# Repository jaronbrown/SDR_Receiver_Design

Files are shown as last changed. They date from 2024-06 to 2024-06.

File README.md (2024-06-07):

# Walla Walla University ENGR357 SDR Design Winter 2024

## Goals
- Continuous Coverage from 5-30 MHz and AM coverage (540-1700 kHz)
- Tune to AM by mixing up to 10.7 MHz then using the Tayloe detector to down-sample to 0-48 kHz

## Design
 - Incorporates a two stage mixing approach in order to achieve wider bandwidth with Si5351 quadrature limitations 
 - Utilizes a Tayloe detector for down-conversion of RF signals.
 - Optional second mixer to bring up AM frequencies (540-1700 kHz) so they can be sampled by Tayloe detector.
 - Input Stage: Automatic Band Pass Filters with optional AM mixer. Includes antenna ground isolation.
 - Output Stage: Quadrature signals amplified with 84 kHz low pass filter. Sampled directly with on-board ADC (48 kHz Nyquist) or output over 3.5mm audio jack. The larger LPF passband (84 kHz) minimizes ripple.
 - Raspberry Pi Pico W Controller with LDO (TPS7A8001DRBR) for cleaner +4V5 (derived from +5V USB).
 - H/W Controlled BPF multiplexors, i2c controlled 3-output VLO (Si5351), and i2s compatible ADC (PCM1808PWR).

## ltspice Simulations
Various core elements of the design were simulated to test their functionality. Notable simulations include a [Monte Carlo simulation](spice/BPF_monte_carlo.asc) of the three bandpass filters (frequency response shown below) to determine effects of component tolerances and a [simulation of the Tayloe detector](spice/Tayloe_test.asc), along with its "differential" amplifiers. The Tayloe detector input is a 1 $\mu V$ sinewave and the output (of the I channel) can be seen in the graph below. In the actual implementation, there is a 1 $\mu F$ blocking capacitor before the ADC and audio jack, but this is omitted for sake of simulation. This would remove the 2.25V DC offset.

Bandpass Filters
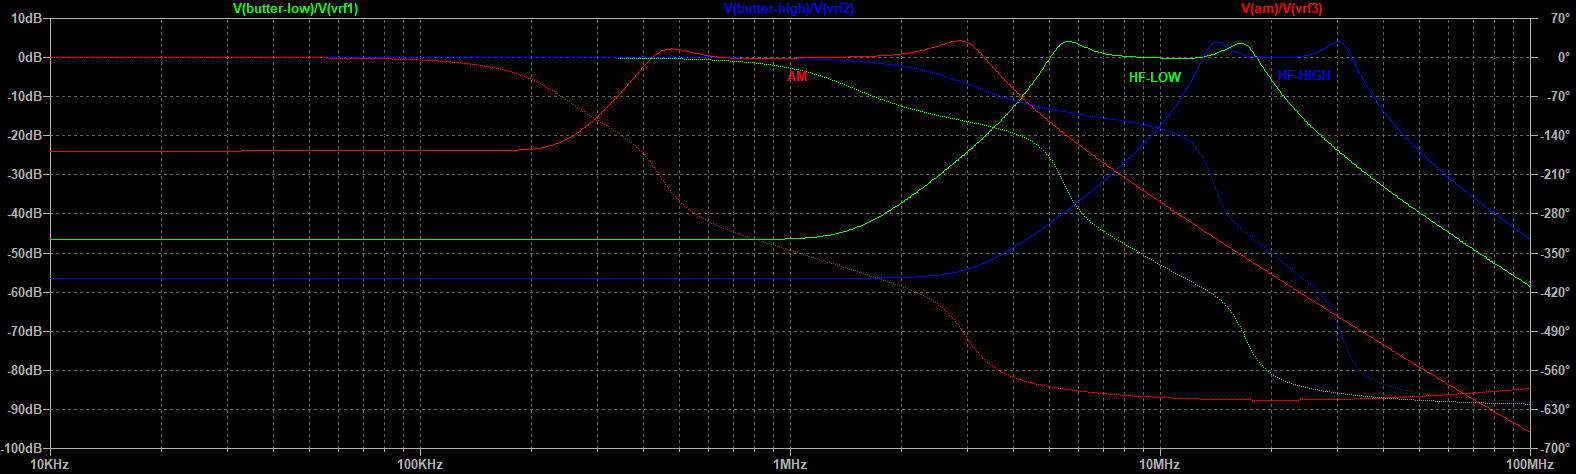
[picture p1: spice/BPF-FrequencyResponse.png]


Tayloe Detector
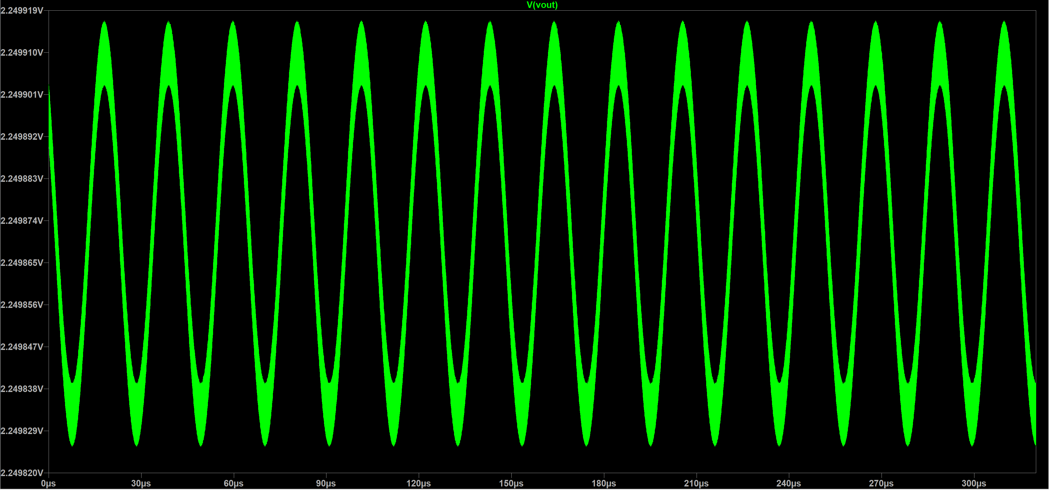
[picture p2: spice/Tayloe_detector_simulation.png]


## Fabrication Information
The boards tested were fabricated by [JLCPCB](jlcpcb.com). They also installed all the surface-mount components--LCSC part numbers included in schematic. Total fabrication cost (including building the boards) from JLCPCB was about $120 USD for 5 boards. The [build plan](BuildPlan.md) was followed for assembling the boards and testing their functionality. The specifications for the inductors and transformer used, can be found in [Inductors](Inductors.md).

## Software
### Python
The software for the Raspberry Pi Pico W consists of three microPython files: [main.py](python/main.py), [radio.py](python/radio.py), and [si5351.py](python/si5351.py). All three files should be loaded onto the Pico.

The microPython module to control the SI5351, [si5351.py](python/si5351.py), was provided by [https://github.com/thaaraak/Tinypico-Radio/tree/master](https://github.com/thaaraak/Tinypico-Radio/tree/master). Some minor changes were made to the ```outputs_enabled``` setter in order to allow individual clock enabling/disabling--used for the AM mixer local oscillator.

The radio control is handled by [radio.py](python/radio.py) which after initializing a ```Radio```, ```run()``` can be used to parse Quisk commands and automatically control bandpass filter selection (based on frequency) and frequency. The bandpass filters can also be controlled manually by entering "BAND,AUTO" to allow for manual testing and use of the built in bypass capacitor. Frequencies from 4-32 MHz are handled via the HF HIGH/LOW BPFs with a single stage of mixing. Frequencies from 0.4-4 MHz are handled via AM mixing (due to the SI5351 not maintaining quadrature below 4 MHz). When switching from AM bands back to HF the SI5351 control is reinitialized to prevent unpredictable clock drift.

Currently there is no support for WiFi control/data transmit, nor is there support for the on-board ADC. This would require migrating to C for DMA. This is coming soon TM.

## Quisk
This SDR is designed to be used with Quisk (https://james.ahlstrom.name/quisk/). Some basic Quisk device configs are provided in [quisk](quisk/). Currently there is no custom widget support for bandpass selection and AM offsets (for tuning away from center).

An optional [Dockerfile](Dockerfile) and sample [start script](startDocker.sh.sample) is provided to run Quisk via Docker--though this requires proper ```/dev/ttyACM0``` permissions, pulseaudio, and xserver. If running on Windows via WSL the aforementioned packages should be installed as well as utilizing usbipd-win (https://james.ahlstrom.name/quisk/) to passthrough the Pico connection.

## Case
stl files for a 3d printable [case](case) are included. Note that because the board does not have any mounting holes the case is a friction fit--consider adjusting tolerances when printing.

## Testing
Testing revealed the radio functions over the planned 10-30 MHz as well as the AM commercial frequencies (using the second mixer), though some signal overlap is apparent for AM. The bandpass filters were characterized using a signal generator and a spectrum analyzer.

### AM Bandpass Filter Characterization
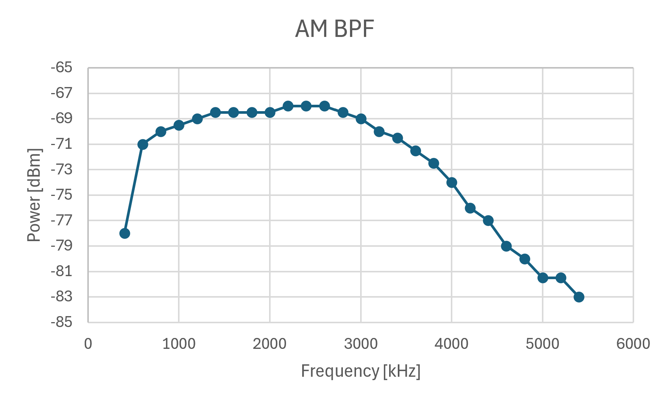
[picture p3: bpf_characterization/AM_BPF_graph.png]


### Low HF Bandpass Filter Characterization
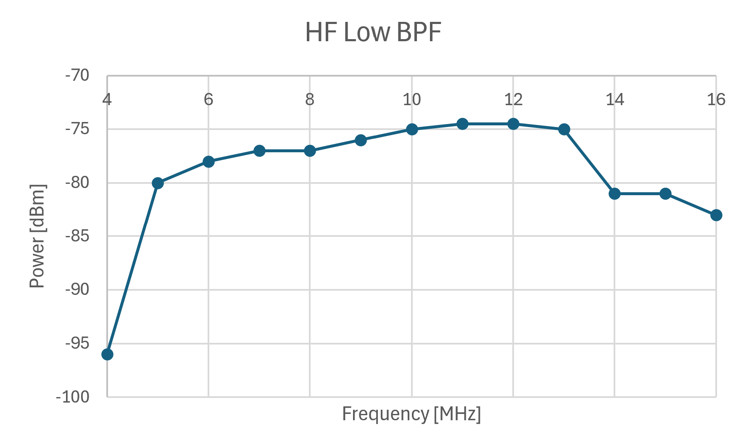
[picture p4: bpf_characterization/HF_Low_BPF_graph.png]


### High HF Bandpass Filter Characterization
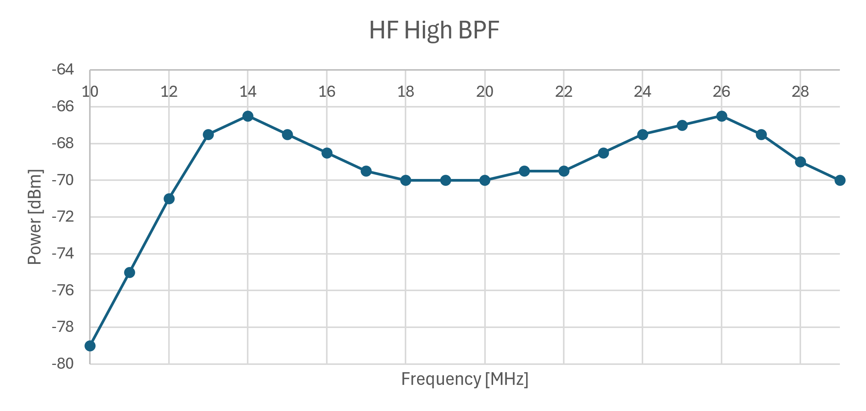
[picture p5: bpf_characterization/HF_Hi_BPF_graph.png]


## KiCAD Schematic
### Complete Block Diagram


### Automatic Band Pass Filter


### AM Handling: Filters and Upconversion


### 3rd Order Butterworth BPF 5-18 MHz


### 3rd Order Butterworth BPF 13-32.7 MHz


### IQ Tayloe Detector & 84kHz IF filter


### SDR Controller


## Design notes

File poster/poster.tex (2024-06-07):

% Gemini theme
% https://github.com/anishathalye/gemini

\documentclass[final]{beamer}

% ====================
% Packages
% ====================

\usepackage[T1]{fontenc}
\usepackage{lmodern}
\usepackage[size=custom,width=121.92,height=91.44,scale=1.0]{beamerposter}
\usetheme{gemini}
\usecolortheme{wwu}
\usepackage{graphicx}
\usepackage{booktabs}
\usepackage{tikz}
\usetikzlibrary{graphs,graphs.standard,arrows.meta}
\usepackage{pgfplots}
\usepackage[square,numbers]{natbib}
\pgfplotsset{compat=1.14}
\usepackage{anyfontsize}

%\usepackage{etoolbox}
\newcommand{\framedtext}[1]{%
\par%
\noindent\fbox{%
    \parbox{\dimexpr\linewidth-2\fboxsep-2\fboxrule}{#1}%
}%
}

% ====================
% Lengths
% ====================

% If you have N columns, choose \sepwidth and \colwidth such that
% (N+1)*\sepwidth + N*\colwidth = \paperwidth
\newlength{\sepwidth}
\newlength{\colwidth}
\setlength{\sepwidth}{0.025\paperwidth}
\setlength{\colwidth}{0.3\paperwidth}

\newcommand{\separatorcolumn}{\begin{column}{\sepwidth}\end{column}}

% ====================
% Title
% ====================

\title{Software-Defined Radio\\ An Electrical Engineering Project}

\author{Jaron Brown \and Ethan Jansen}

\institute[shortinst]{Edward F. Cross School of Engineering, Walla Walla University, College Place, Washington}

% ====================
% Footer (optional)
% ====================

\footercontent{
  \href{https://gitlab.cs.wallawalla.edu/browja/engr357-receiver-design}{https://gitlab.cs.wallawalla.edu/browja/engr357-receiver-design}
  %\hfill\href{mailto:email@wallawalla.edu}{email@wallawalla.edu}
}
% (can be left out to remove footer)

% ====================
% Logo (optional)
% ====================

% use this to include logos on the left and/or right side of the header:
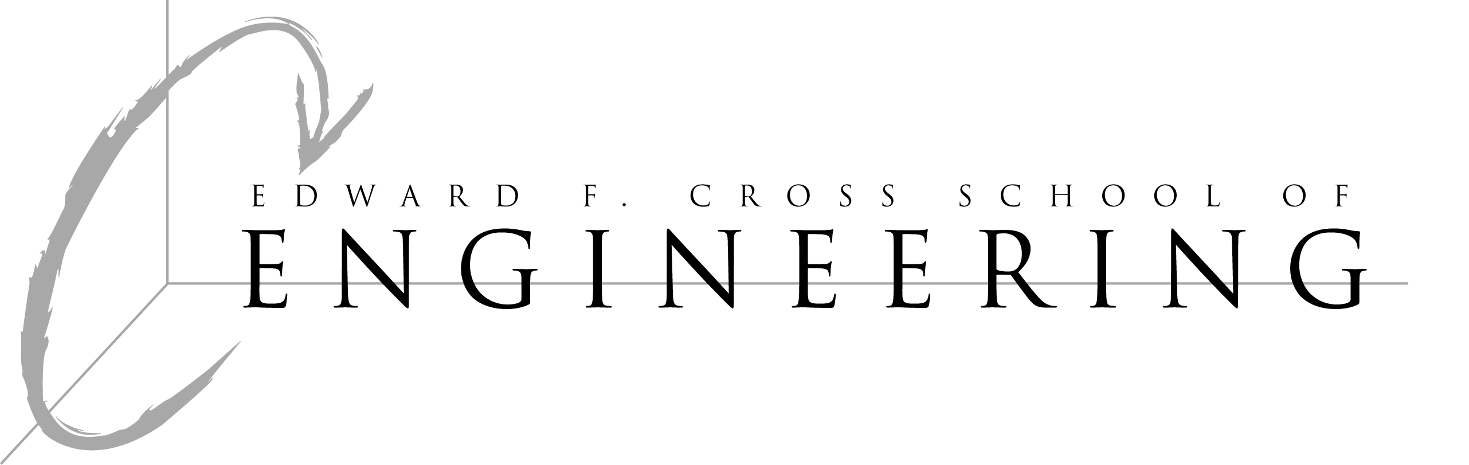
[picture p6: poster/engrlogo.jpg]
\logoright{}
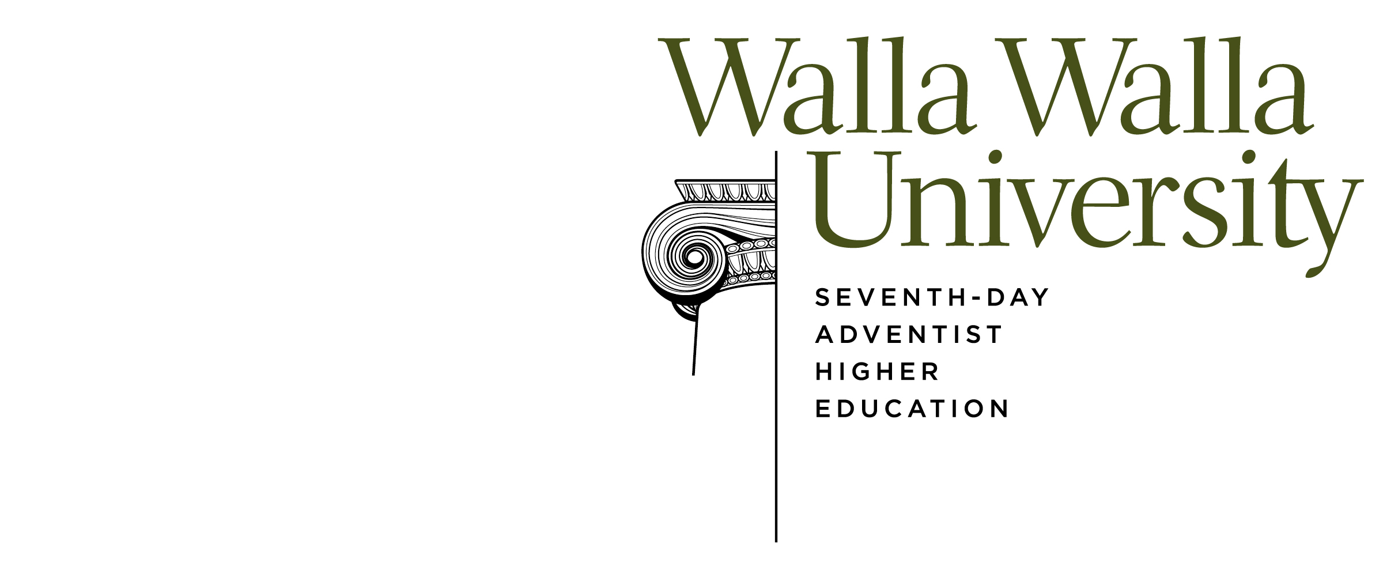
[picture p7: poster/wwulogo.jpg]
\logoleft{}

% ====================
% Body
% ====================

\begin{document}

\begin{frame}[t]
\begin{columns}[t]
\separatorcolumn

\begin{column}{\colwidth}

  \begin{exampleblock}{Introduction}

    \begin{figure}
      \centering
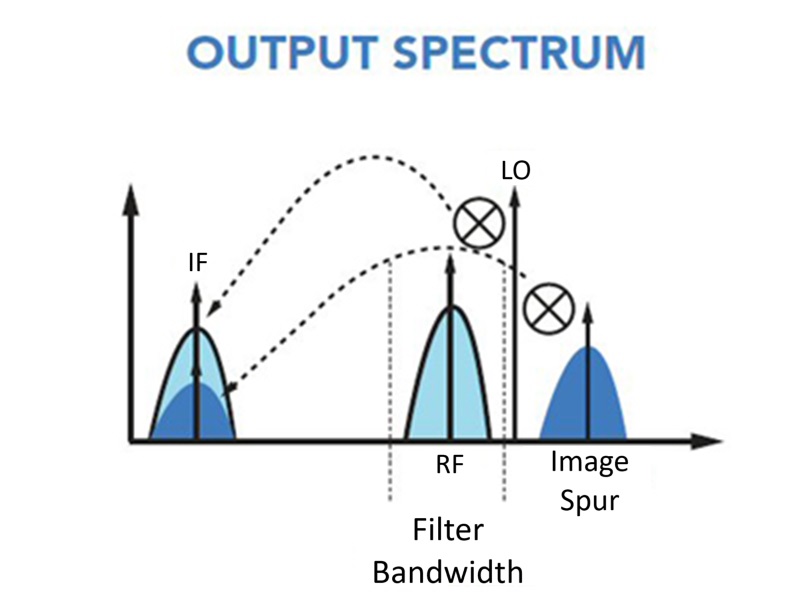
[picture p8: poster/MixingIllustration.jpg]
      
      \caption{Mixing a radio frequency (RF) signal down to an intermediate frequency (IF) (audio) signal. Shows a spur being mixed down to the same IF as the desired signal as it is the same distance from the local oscillator (LO) frequency as RF. \cite{mixing}}
    \end{figure}
    
  \end{exampleblock}

  \begin{block}{Section 1}

  \end{block}

  \begin{block}{Section 2}

  \end{block}

\end{column}

\separatorcolumn

\begin{column}{\colwidth}

  \begin{block}{Section 1}
    
    \begin{figure}
      \centering
      
      \caption{SDR Schematic showing the analog quadrature mixer (left) and the digital controller (right).}
    \end{figure}

    \begin{figure}
      \centering
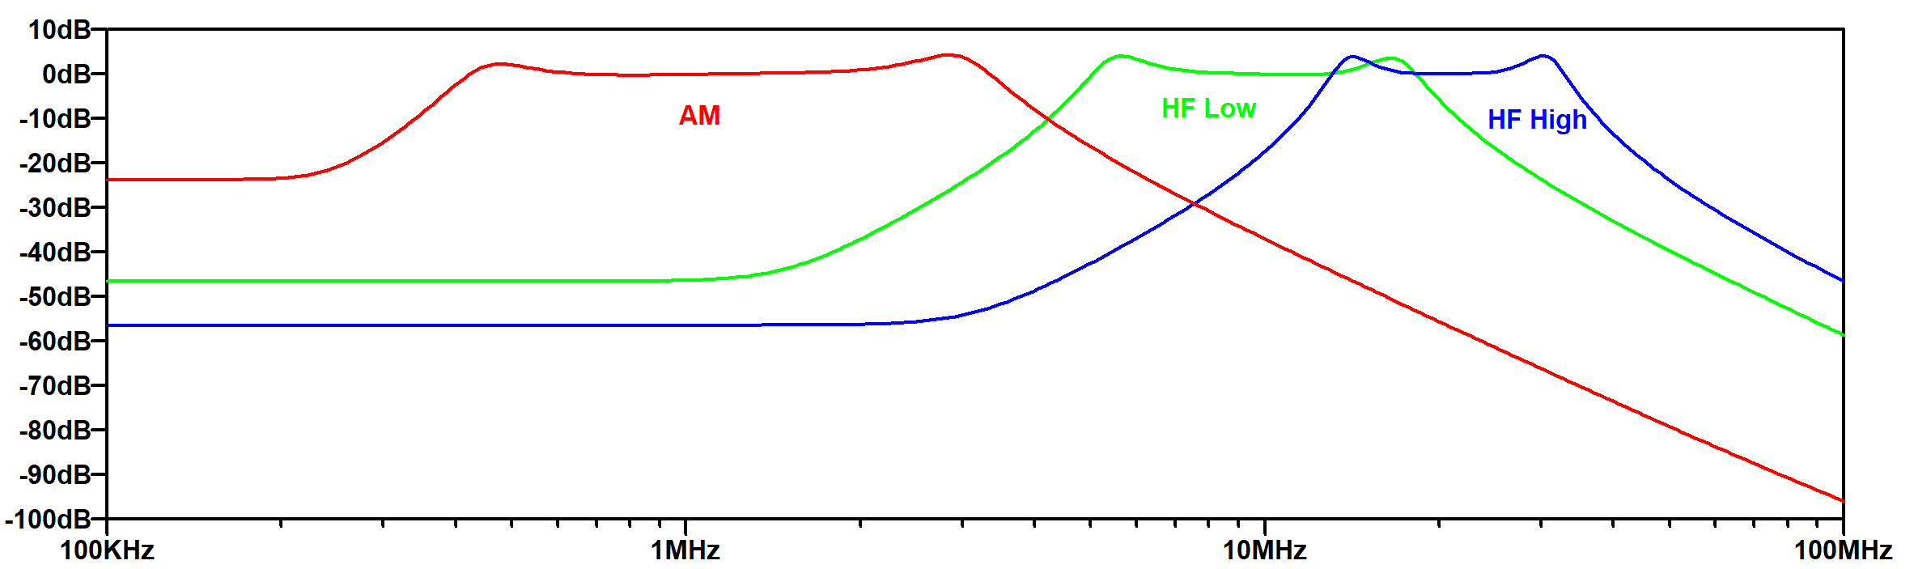
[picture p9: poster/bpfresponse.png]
      
      \caption{Simulation of the different band-pass filters.}
    \end{figure}

    \begin{figure}
      \centering
      
      \caption{SDR circuit board layout. Shows the part locations and traces connecting them.}
    \end{figure}

    \begin{figure}
      \centering
      
      \caption{The completed SDR. A physical, fully manufactured board.}
    \end{figure}

  \end{block}

  \begin{block}{Section 2}

  \end{block}

\end{column}

\separatorcolumn

\begin{column}{\colwidth}

  \begin{block}{Section 1}

    \begin{figure}
      \centering
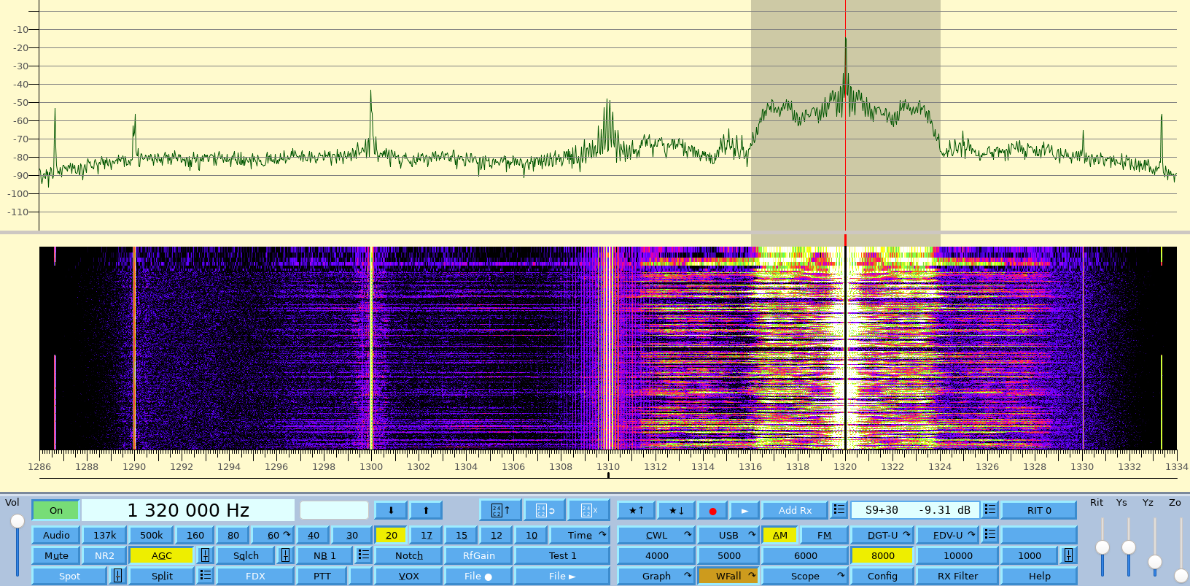
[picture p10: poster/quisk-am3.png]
      
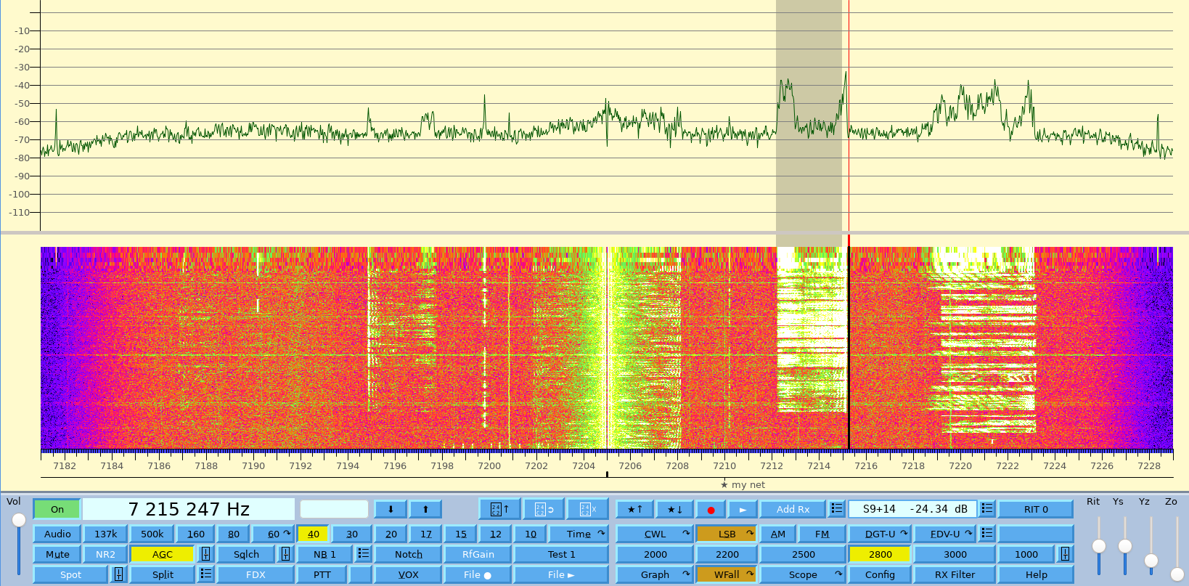
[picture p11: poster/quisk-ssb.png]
      
      \caption{Quisk SDR software \cite{quisk}. Shows the waterfall display, the audio spectrum, and device control. (Top) AM demodulation at 1.3MHz. (Bottom) SSB demodulation at 7.2MHz.}
    \end{figure}

  \end{block}
  
  \begin{block}{Section 2}

  \end{block}

  \begin{block}{References}

    \nocite{*} % don't cite everything
    \footnotesize{\bibliographystyle{plain}\bibliography{poster}}

  \end{block}

\end{column}

\separatorcolumn
\end{columns}
\end{frame}

\end{document}

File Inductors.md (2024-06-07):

| ID | Value | Freq. Range (Mhz) | Core | Turns | Wire Length (cm)|
|:--:|:-----:|:---:|:----:|:-----:|:---:|
| T1 | 1:1 - 500 $\Omega$ | 0.4-30 | FT37-43 | 24 | 36 |
| L1, L3 | 620nH | 5-18 | T37-6 | 14 | 23 |
| L2 | 560nH | 5-18 | T37-6 | 14 | 23 |
| L4, L6 | 2.7uH | 0.4-3.3 | T50-2 | 23 | 46 |
| L5 | 9.1uH | 0.4-3.3 | T50-2 | 43 | 79 |
| L7, L9 | 390nH | 13-33 | T37-6 | 11 | 20 |
| L8 | 180nH | 13-33 | T37-6 | 8 | 15 |

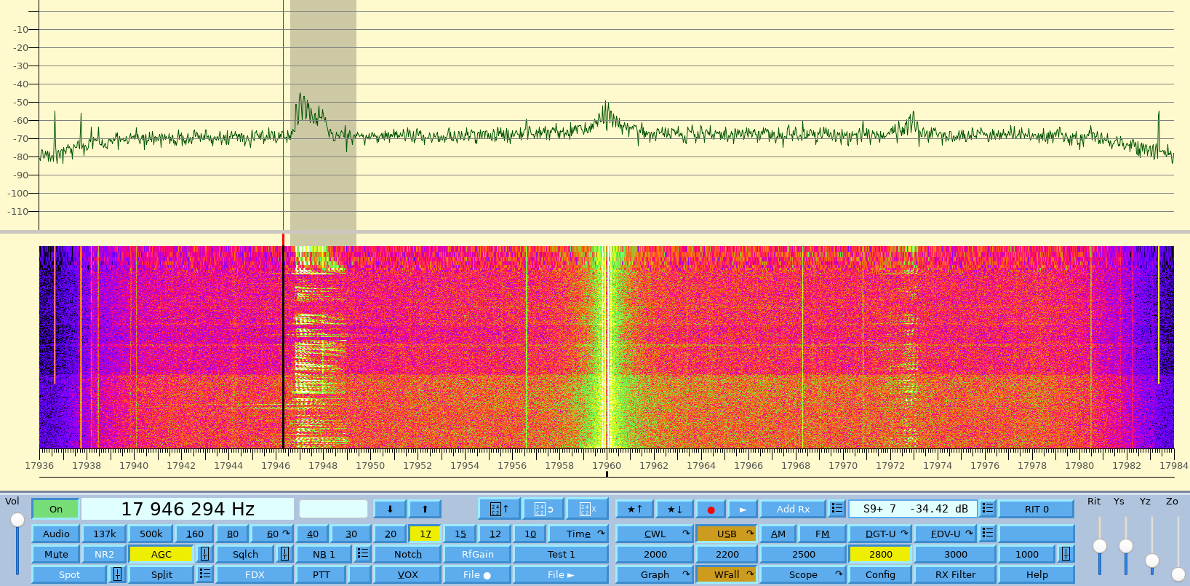
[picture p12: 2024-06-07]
poster/quisk-ssb3.png

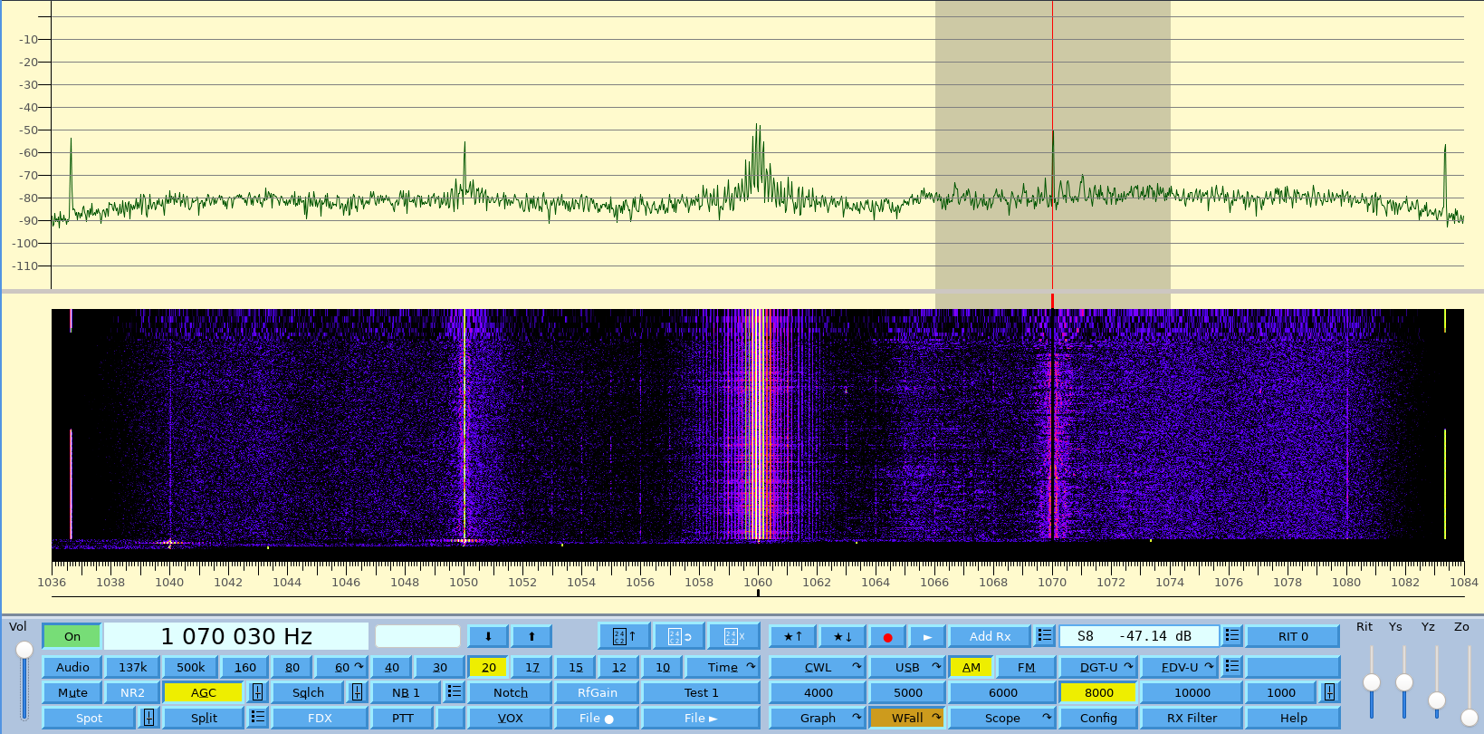
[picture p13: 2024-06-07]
poster/quisk-am.png

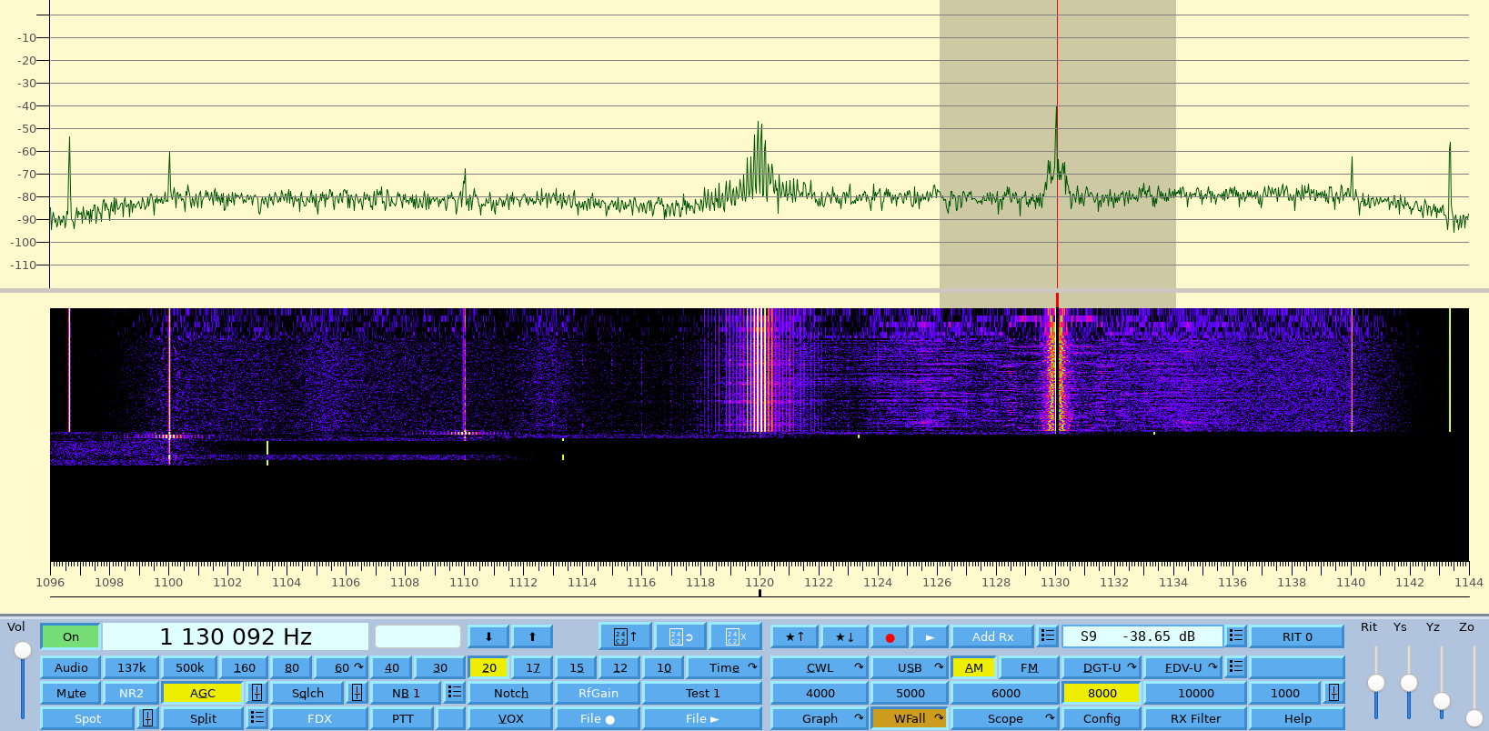
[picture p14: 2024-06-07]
poster/quisk-am2.png

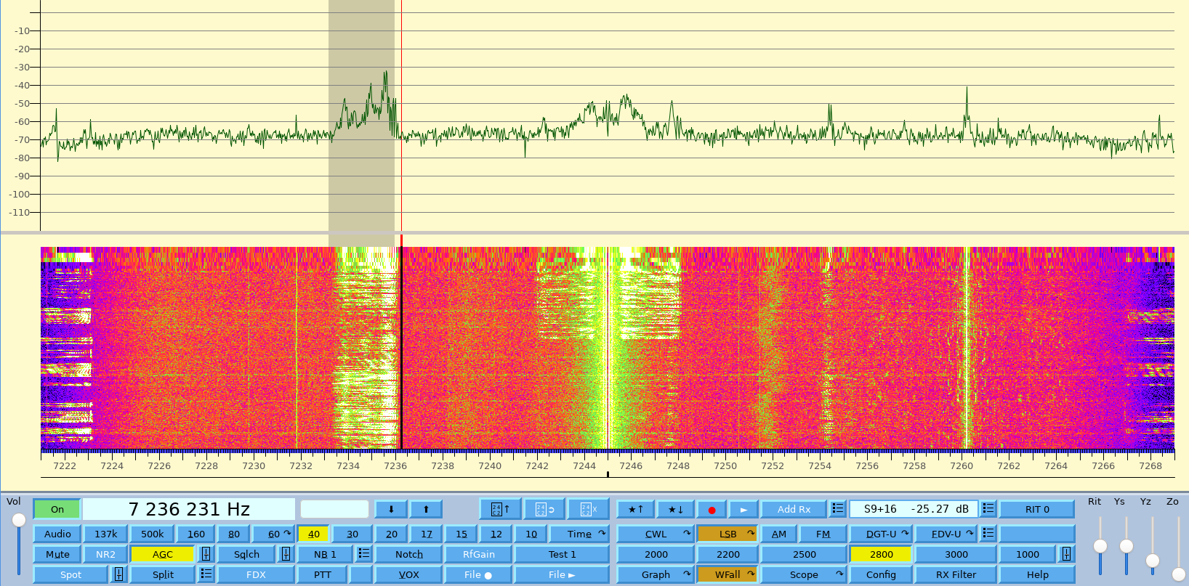
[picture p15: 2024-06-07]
poster/quisk-ssb2.png

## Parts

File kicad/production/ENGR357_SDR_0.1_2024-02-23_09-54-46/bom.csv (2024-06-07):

Designator | Footprint | Quantity | Value | LCSC Part #
C1, C11, C13, C14, C15, C17, C18, C29, C3, C38, C39, C5, C6, C9 | 0805 | 14 | 0.1u | C49678
C10 | 0603 | 1 | 0.01u | C57112
C12 | 0603 | 1 | 4.7u | C19666
C16, C2, C4, C7 | 0805 | 4 | 10u | C15850
C19, C20, C21, C22, C23, C24, C25, C26 | 0603 | 8 | 4.7n | C883564
C27, C28 | 0402 | 2 | 270p | C881990
C30, C31 | 0805 | 2 | 1u | C28323
C32, C33, C34 | 0805 | 3 | 470p | C1743
C35, C37 | 0603 | 2 | 6.8n | C1631
C36 | 0805 | 1 | 2.2n | C28260
C40, C42 | 0603 | 2 | 150p | C1594
C41 | 0603 | 1 | 330p | C1664
D1, D2 | D_SOD-123 | 2 | B5819W SL | C8598
JP3 | SolderJumper-2_P1.3mm_Open_RoundedPad1.0x1.5mm | 1 | GND_Isolation
POST_XSTAL, PRE_XSTAL, TP1, TP10, TP11, TP12, TP13, TP14, TP15, TP16, TP19, TP2, TP20, TP21, TP22, TP23, TP24, TP25, TP26, TP27, TP28, TP29, TP3, TP30, TP31, TP32, TP33, TP34, TP35, TP4, TP5, TP6, TP7, TP8, TP9 | TestPoint_THTPad_D1.0mm_Drill0.5mm | 35 | TestPoint
R1, R10, R14, R2, R21 | 0805 | 5 | 10k | C17414
R11, R12, R13, R15, R16, R17, R18, R3, R4, R5, R6 | 0805 | 11 | 0 | C17477
R19, R20 | 0805 | 2 | 5.1k | C27834
R22, R26 | 0805 | 2 | 47 | C17714
R23 | 0805 | 1 | 51 | C17738
R24, R25, R7, R8 | 0805 | 4 | 4.7k | C17673
R9 | 0805 | 1 | 47k | C17713
SW1 | SW_Push_1P1T_XKB_TS-1187A | 1 | SW_Push | C318884
U1 | PW14 | 1 | PCM1808PWR | C55513
U10, U8 | MSOP-8_3x3mm_P0.65mm | 2 | ADA4805-2ARMZ | C208293
U3 | DRB0008A-MFG | 1 | TPS7A8001DRBR | C105265
U4 | MSOP-10_3x3mm_P0.5mm | 1 | Si5351A-B-GT | C5451727
U5, U6, U7, U9 | SOP65P640X120-16N | 4 | SN74CBT3253 | C2674672
Y1 | Crystal_SMD_3225-4Pin_3.2x2.5mm | 1 | 27Mhz 10pF | C5210645

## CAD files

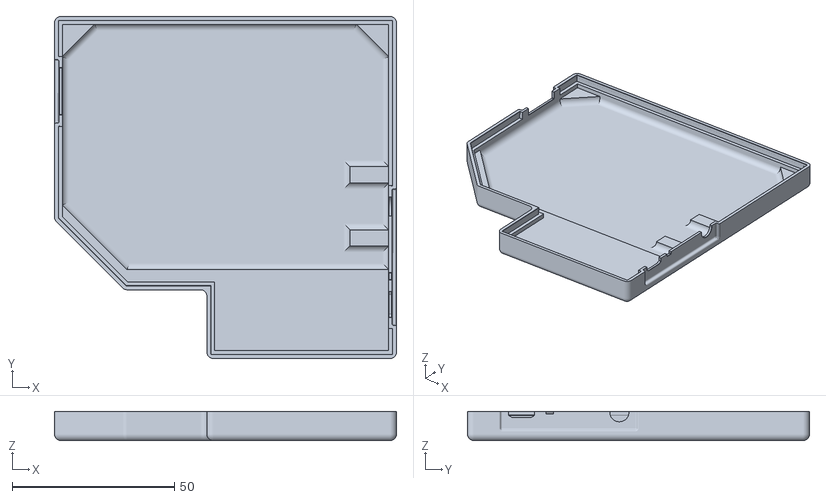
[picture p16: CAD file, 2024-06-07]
case/SDR-Case-Bottom.stl
105.5 x 105.5 x 9.00

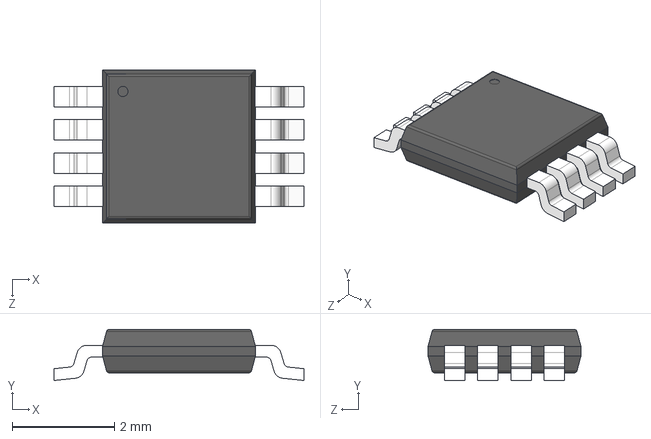
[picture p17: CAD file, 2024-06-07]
kicad/ADA4805-2ARMZ/3D/ADA4805-2ARMZ.stp
4.90 x 1.00 x 3.00 mm

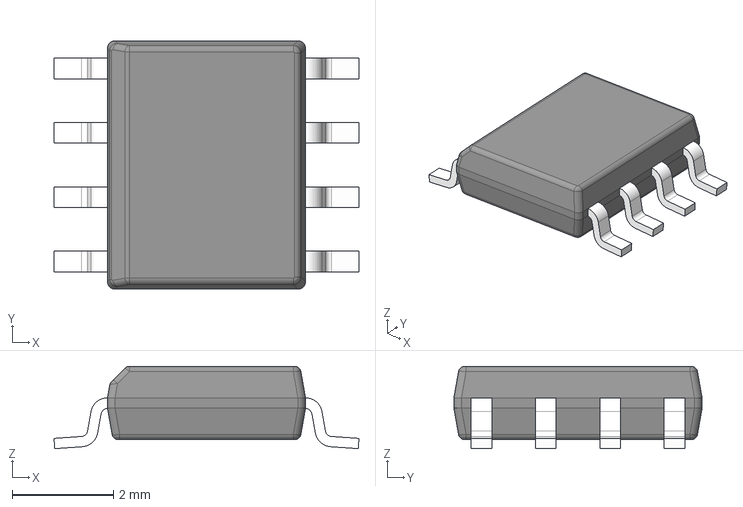
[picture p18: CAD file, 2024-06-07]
kicad/OPA1612AIDR/3D/OPA1612AIDR.stp
6.02 x 4.90 x 1.63 mm
BODY-SO
LEAD-D0008A x 8

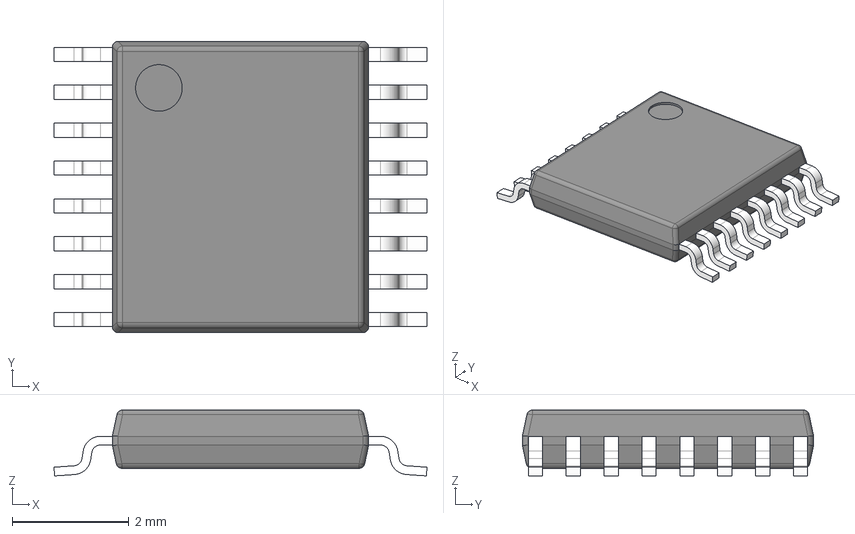
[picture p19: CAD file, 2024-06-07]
kicad/SN74CBT3253CPWR/3D/SN74CBT3253CPWR.stp
6.40 x 5.00 x 1.13 mm
BODY-TSSOP
LEAD-TSSOP x 16
PIN1

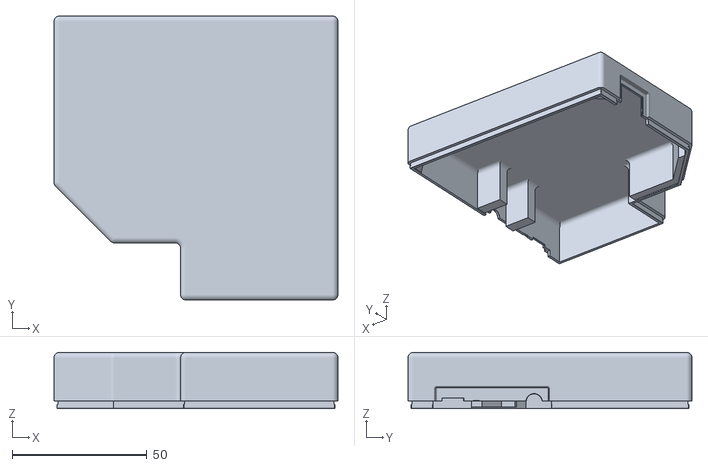
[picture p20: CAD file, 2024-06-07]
case/SDR-Case-Top.stl
105.5 x 105.5 x 20.9

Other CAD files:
kicad/ADA4805-2ARMZ/Allegro/sop65p490x110-8n.psm
kicad/ADA4805-2ARMZ/DEHDL/ada4805_2armz/chips/chips.prt
kicad/OPA1612AIDR/Allegro/soic127p600x175-8n.psm
kicad/OPA1612AIDR/DEHDL/opa1612aidr/chips/chips.prt
kicad/SN74CBT3253CPWR/Allegro/sop65p640x120-16n.psm
kicad/SN74CBT3253CPWR/DEHDL/sn74cbt3253cpwr/chips/chips.prt

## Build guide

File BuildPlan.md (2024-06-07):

## Walla Walla University ENGR357 Board Bring-up Plan Winter 2024

### Build Plan
- Wind inductors for band-pass filters and IF filters in addition to the transformer and measure inductance
- Solder BNC, 3.5mm audio jack, Raspberry Pi Pico W, crystal, inductors, and transformer
- Flash firmware to Pico W
- *Test ADC (Stretch Goal)*

### Testing Proceedure
- Check that PWR and GND planes are not connected X
- Continuity checks X
- Check LDO X
- Test functionality of Si5351 programmable oscillator by programming with Pico and measuring clocks directly from test points
- Test the selectable filter switches X
- Test Tayloe detector functionality by driving mux with the Si5351 and supplying a tone from a signal generator as the RF input through bypass capacitor
- Test the IF filtering and gain of the Tayloe detector and subsequent stages by sweeping the frequency of the signal generator
- Test the frequency response of the two BPFs and the BPF before the AM mixer
- Test quisk control
- Check for ground loops
- Test the frequency response of the crystal filter
- Test the AM switching mixer in a similar manner to the Tayloe detector

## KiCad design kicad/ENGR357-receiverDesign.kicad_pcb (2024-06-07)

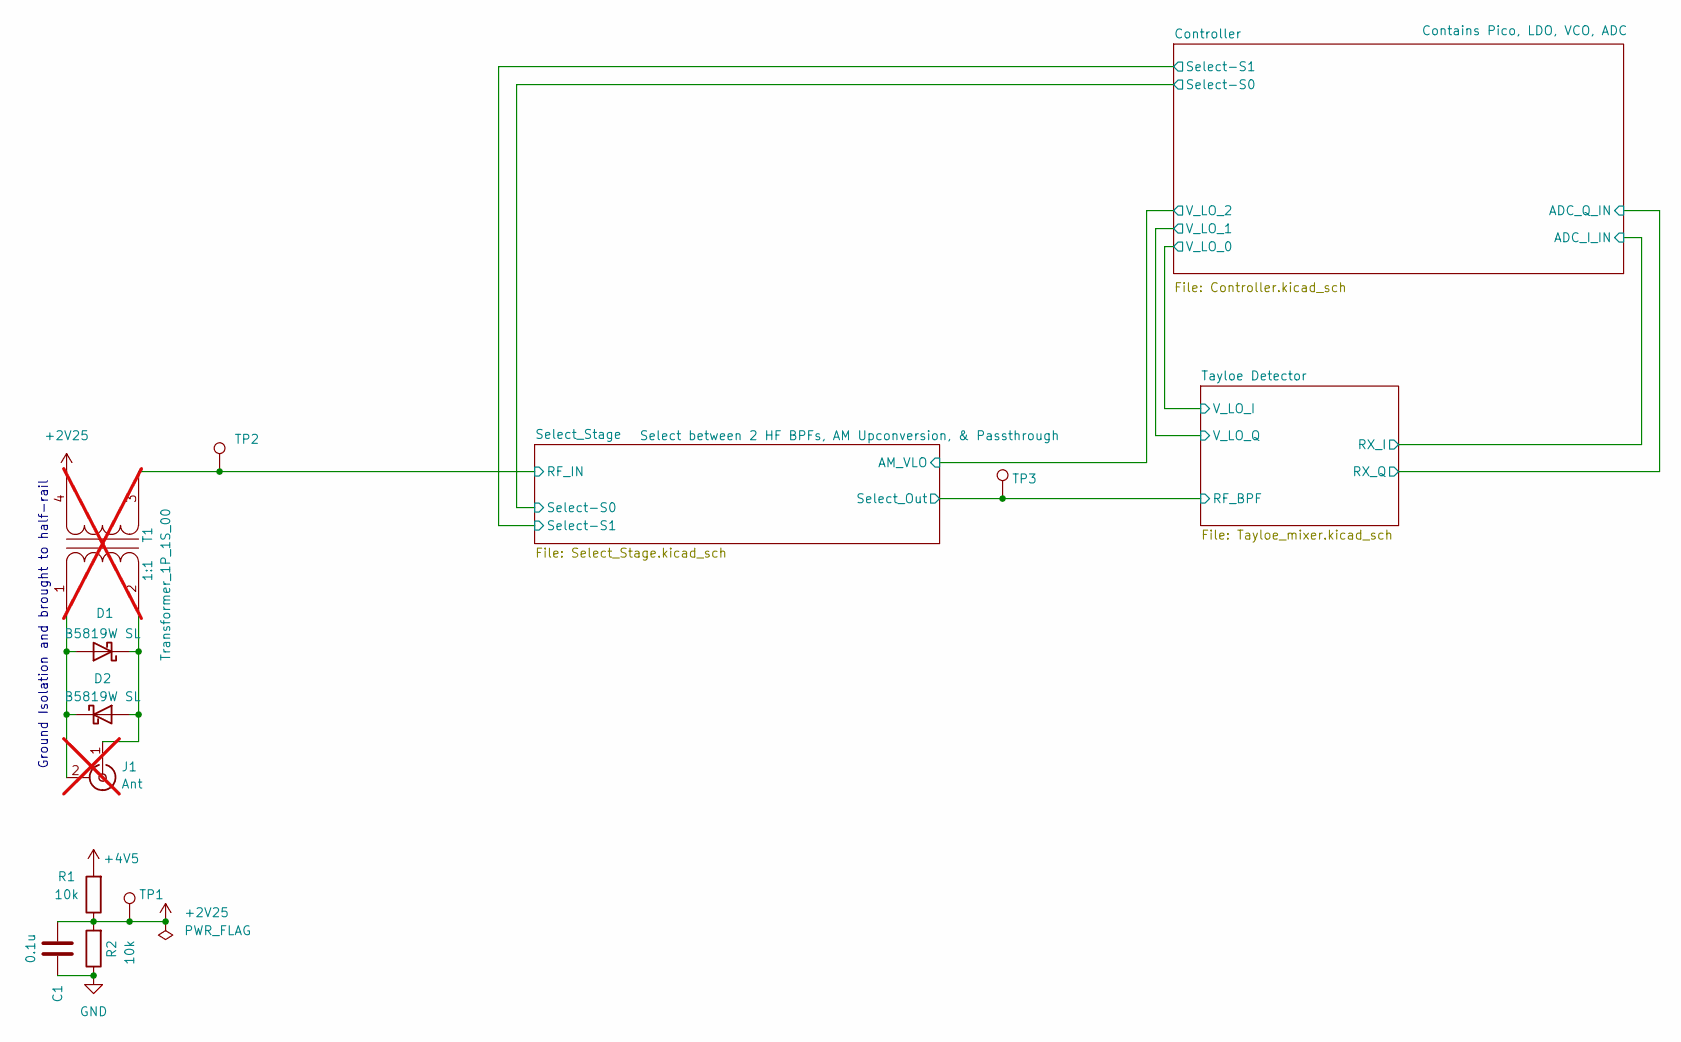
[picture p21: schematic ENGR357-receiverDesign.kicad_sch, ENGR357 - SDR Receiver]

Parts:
C1: 0.1u; C_0805_2012Metric; LCSC C49678
D1, D2: B5819W SL; D_SOD-123; LCSC C8598
J1: Ant; BNC_Amphenol_B6252HB-NPP3G-50_Horizontal; not fitted
R1, R2: 10k; R_0805_2012Metric; LCSC C17414
T1: Transformer_1P_1S_00; Transformer_Toroid_Horizontal_D10.5mm_Amidon-T37; not fitted
TP1, TP2, TP3: TestPoint; TestPoint_THTPad_D1.0mm_Drill0.5mm

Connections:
+2V25: C1.2, R1.1, R2.2, T1.4 (SB), TP1.1; also elsewhere on the board
+4V5: R1.2; also elsewhere on the board
/Select_Stage/RF_IN: T1.3 (SA), TP2.1; also elsewhere on the board
/Select_Stage/Select_Out: TP3.1; also elsewhere on the board
GND: C1.1, R2.1; also elsewhere on the board
unnamed: D1.2 (A), D2.1 (K), J1.2 (Ext), T1.1 (AA)
unnamed: D1.1 (K), D2.2 (A), J1.1 (In), T1.2 (AB)

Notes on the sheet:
Ground Isolation and brought to half-rail

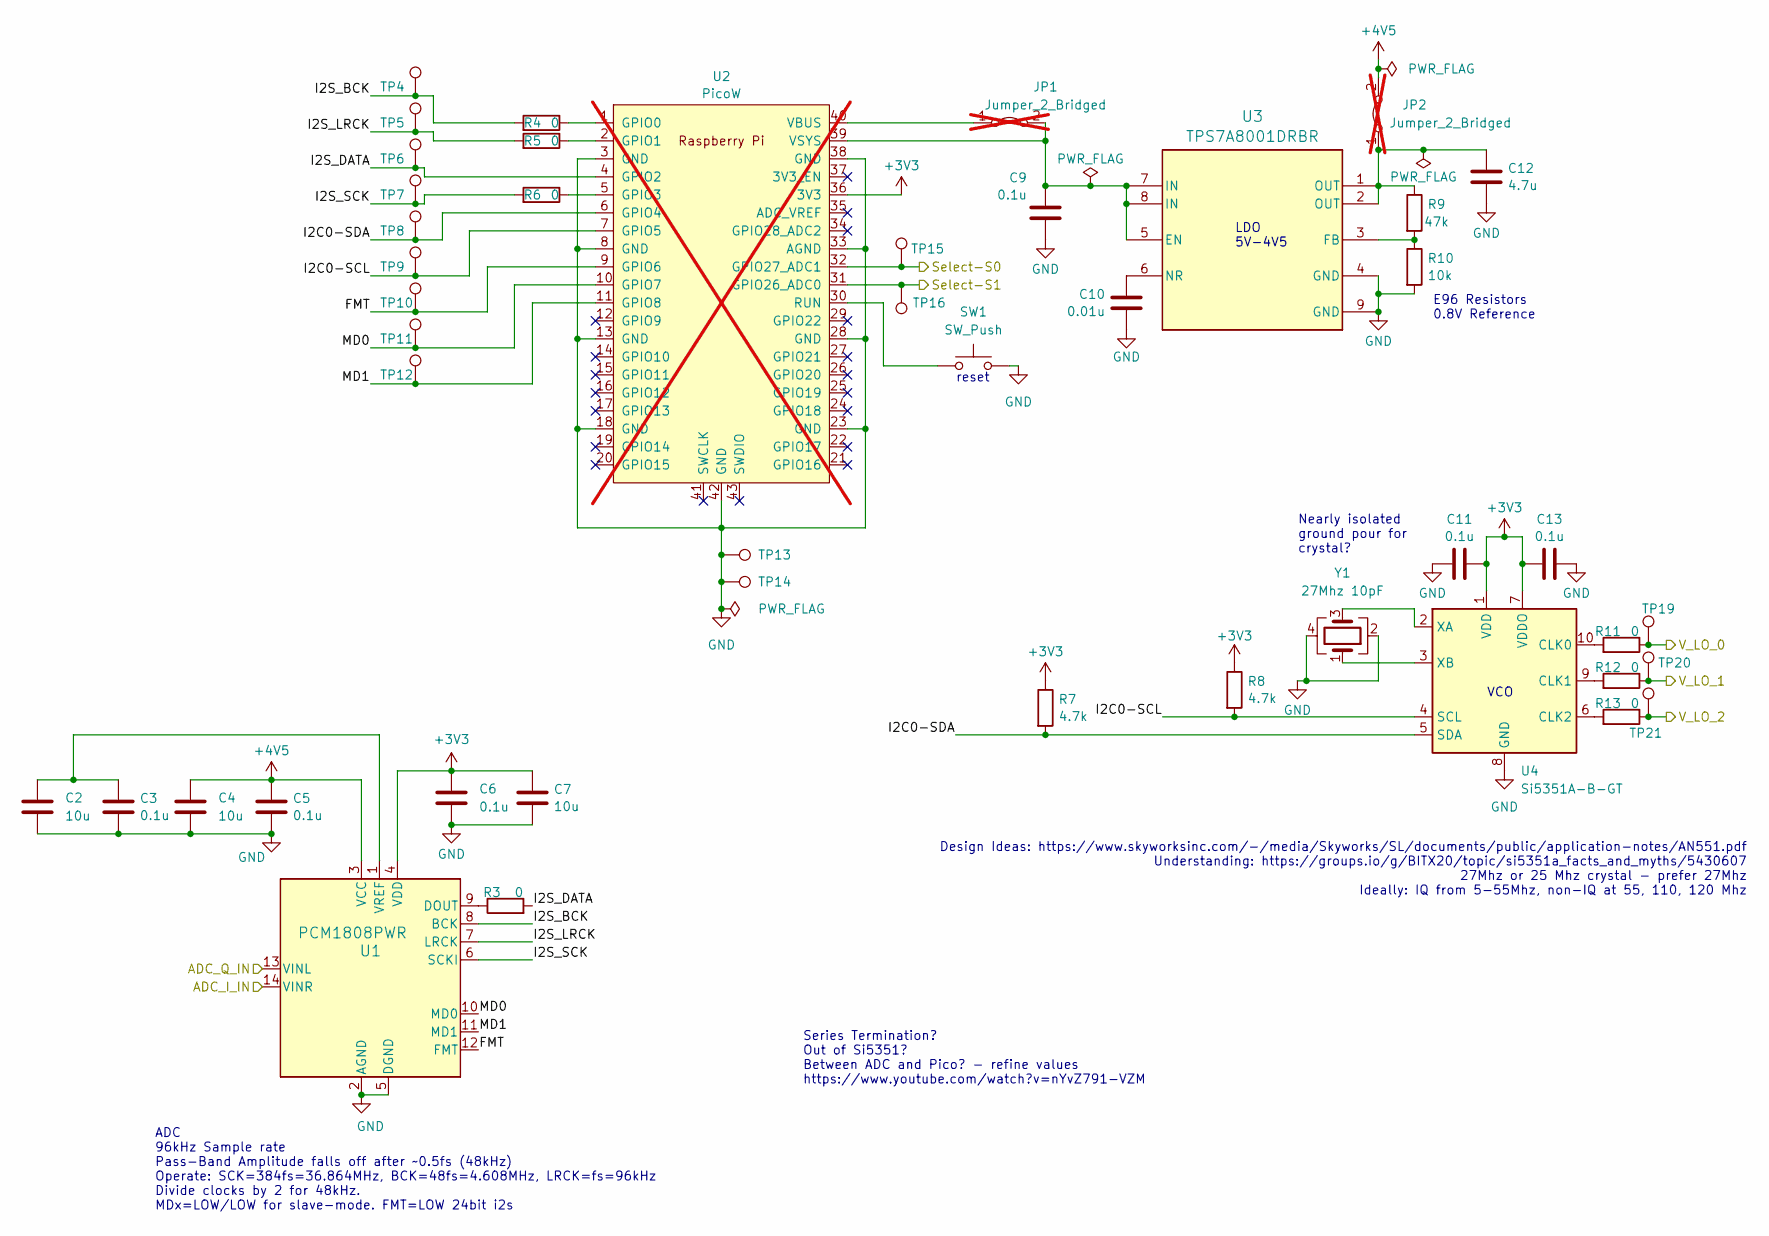
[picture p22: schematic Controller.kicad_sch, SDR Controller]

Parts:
C2, C4, C7: 10u; C_0805_2012Metric; LCSC C15850
C3, C5, C6, C9, C11, C13: 0.1u; C_0805_2012Metric; LCSC C49678
C10: 0.01u; C_0603_1608Metric; LCSC C57112
C12: 4.7u; C_0603_1608Metric; LCSC C19666
JP1, JP2: Jumper_2_Bridged; PinHeader_1x02_P2.54mm_Vertical; not fitted
R3, R4, R5, R6, R11, R12, R13: 0; R_0805_2012Metric; LCSC C17477
R7, R8: 4.7k; R_0805_2012Metric; LCSC C17673
R9: 47k; R_0805_2012Metric; LCSC C17713
R10: 10k; R_0805_2012Metric; LCSC C17414
SW1: SW_Push; SW_Push_1P1T_XKB_TS-1187A; LCSC C318884
TP4, TP5, TP6, TP7, TP8, TP9, TP10, TP11, TP12, TP13, TP14, TP15, TP16, TP19, TP20, TP21: TestPoint; TestPoint_THTPad_D1.0mm_Drill0.5mm
U1: PCM1808PWR; PW14; LCSC C55513
U2: PicoW; RPi_PicoW_SMD_TH; not fitted
U3: TPS7A8001DRBR; DRB0008A-MFG; LCSC C105265
U4: Si5351A-B-GT; MSOP-10_3x3mm_P0.5mm; LCSC C5451727
Y1: 27Mhz 10pF; Crystal_SMD_3225-4Pin_3.2x2.5mm; LCSC C5210645

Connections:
+3V3: C6.1, C7.1, C11.2, C13.1, R7.1, R8.1, U1.4 (VDD), U2.36 (3V3), U4.1 (VDD), U4.7 (VDDO); also elsewhere on the board
+4V5: C4.1, C5.1, JP2.2 (B), U1.3 (VCC); also elsewhere on the board
/Controller/ADC_I_IN: U1.14 (VINR); also elsewhere on the board
/Controller/ADC_Q_IN: U1.13 (VINL); also elsewhere on the board
/Controller/FMT: TP10.1, U1.12 (FMT), U2.9 (GPIO6); also elsewhere on the board
/Controller/I2C0-SCL: R8.2, TP9.1, U2.7 (GPIO5), U4.4 (SCL); also elsewhere on the board
/Controller/I2C0-SDA: R7.2, TP8.1, U2.6 (GPIO4), U4.5 (SDA); also elsewhere on the board
/Controller/I2S_BCK: R4.2, TP4.1, U1.8 (BCK)
/Controller/I2S_DATA: R3.2, TP6.1, U2.4 (GPIO2); also elsewhere on the board
/Controller/I2S_LRCK: R5.2, TP5.1, U1.7 (LRCK)
/Controller/I2S_SCK: R6.2, TP7.1, U1.6 (SCKI)
/Controller/MD0: TP11.1, U1.10 (MD0), U2.10 (GPIO7); also elsewhere on the board
/Controller/MD1: TP12.1, U1.11 (MD1), U2.11 (GPIO8); also elsewhere on the board
/Controller/Select-S0: TP15.1, U2.32 (GPIO27_ADC1); also elsewhere on the board
/Controller/Select-S1: TP16.1, U2.31 (GPIO26_ADC0); also elsewhere on the board
/Controller/V_LO_0: R11.1, TP19.1; also elsewhere on the board
/Controller/V_LO_1: R12.1, TP20.1; also elsewhere on the board
/Controller/V_LO_2: R13.1, TP21.1; also elsewhere on the board
GND: C2.2, C3.2, C4.2, C5.2, C6.2, C7.2, C9.2, C10.2, C11.1, C12.2, C13.2, R10.2, SW1.2, TP13.1, TP14.1, U1.2 (AGND), U1.5 (DGND), U2.3 (GND), U2.8 (GND), U2.13 (GND), U2.18 (GND), U2.23 (GND), U2.28 (GND), U2.33 (AGND), U2.38 (GND), U2.42 (GND), U3.4 (GND), U3.9 (GND), U4.8 (GND), Y1.2, Y1.4; also elsewhere on the board
unnamed 42: JP1.1 (A), U2.40 (VBUS); also elsewhere on the board
unnamed 43: C9.1, JP1.2 (B), U2.39 (VSYS), U3.5 (EN), U3.7 (IN), U3.8 (IN); also elsewhere on the board
unnamed: C12.1, JP2.1 (A), R9.1, U3.1 (OUT), U3.2 (OUT)
unnamed: R3.1, U1.9 (DOUT)
unnamed: C2.1, C3.1, U1.1 (VREF)
unnamed 50: R4.1, U2.1 (GPIO0); also elsewhere on the board
unnamed 51: R5.1, U2.2 (GPIO1); also elsewhere on the board
unnamed 52: R6.1, U2.5 (GPIO3); also elsewhere on the board
unnamed 53: SW1.1, U2.30 (RUN); also elsewhere on the board
unnamed: R9.2, R10.1, U3.3 (FB)
unnamed: C10.1, U3.6 (NR)
unnamed: R11.2, U4.10 (CLK0)
unnamed: R12.2, U4.9 (CLK1)
unnamed: R13.2, U4.6 (CLK2)
unnamed: U4.2 (XA), Y1.3
unnamed: U4.3 (XB), Y1.1

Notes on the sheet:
Nearly isolated ground pour for crystal?
LDO 5V-4V5
Series Termination? Out of Si5351? Between ADC and Pico? - refine values https://www.youtube.com/watch?v=nYvZ791-VZM
Design Ideas: https://www.skyworksinc.com/-/media/Skyworks/SL/documents/public/application-notes/AN551.pdf Understanding: https://groups.io/g/BITX20/topic/si5351a_facts_and_myths/5430607 27Mhz or 25 Mhz crystal - prefer 27Mhz Ideally: IQ from 5-55Mhz, non-IQ at 55, 110, 120 Mhz
reset
ADC 96kHz Sample rate Pass-Band Amplitude falls off after ~0.5fs (48kHz) Operate: SCK=384fs=36.864MHz, BCK=48fs=4.608MHz, LRCK=fs=96kHz Divide clocks by 2 for 48kHz. MDx=LOW/LOW for slave-mode. FMT=LOW 24bit i2s
VCO
E96 Resistors 0.8V Reference

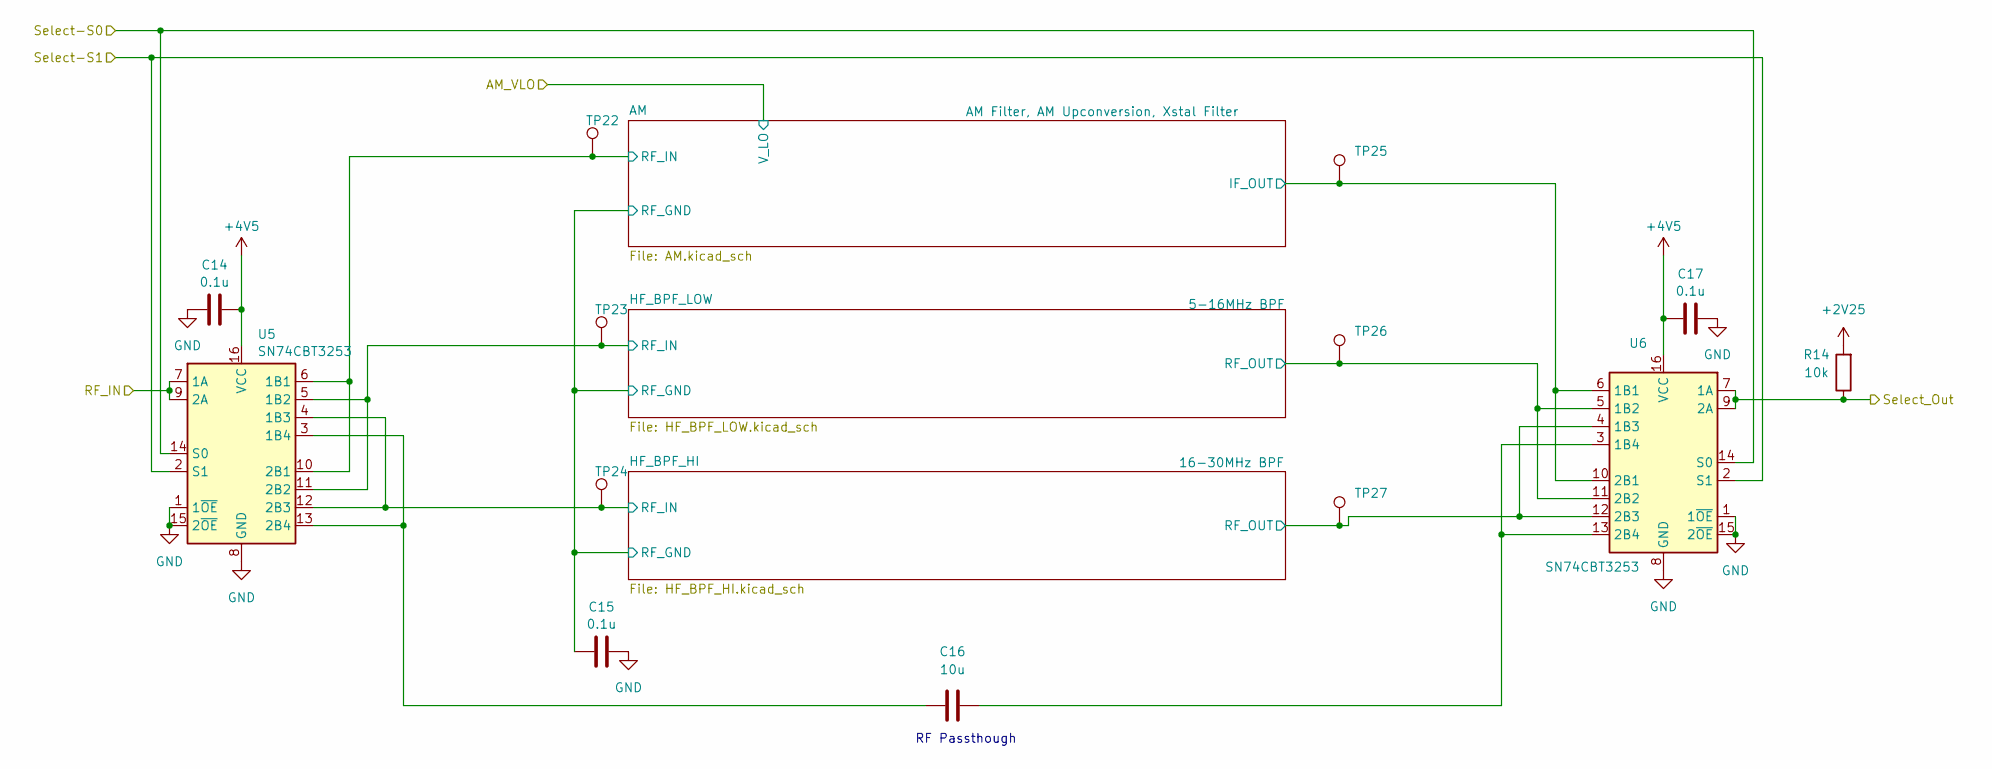
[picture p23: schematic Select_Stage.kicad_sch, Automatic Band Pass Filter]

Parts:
C14, C15, C17: 0.1u; C_0805_2012Metric; LCSC C49678
C16: 10u; C_0805_2012Metric; LCSC C15850
R14: 10k; R_0805_2012Metric; LCSC C17414
TP22, TP23, TP24, TP25, TP26, TP27: TestPoint; TestPoint_THTPad_D1.0mm_Drill0.5mm
U5, U6: SN74CBT3253; SOP65P640X120-16N; LCSC C2674672

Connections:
+2V25: R14.2; also elsewhere on the board
+4V5: C14.2, C17.2, U5.16 (VCC), U6.16 (VCC); also elsewhere on the board
/Controller/Select-S0: U5.14 (S0), U6.14 (S0); also elsewhere on the board
/Controller/Select-S1: U5.2 (S1), U6.2 (S1); also elsewhere on the board
/Select_Stage/AM/IF_OUT: TP25.1, U6.6 (1B1), U6.10 (2B1); also elsewhere on the board
/Select_Stage/AM/RF_GND: C15.1; also elsewhere on the board
/Select_Stage/AM/RF_IN: TP22.1, U5.6 (1B1), U5.10 (2B1); also elsewhere on the board
/Select_Stage/HF_BPF_HI/RF_IN: TP24.1, U5.4 (1B3), U5.12 (2B3); also elsewhere on the board
/Select_Stage/HF_BPF_HI/RF_OUT: TP27.1, U6.4 (1B3), U6.12 (2B3); also elsewhere on the board
/Select_Stage/HF_BPF_LOW/RF_IN: TP23.1, U5.5 (1B2), U5.11 (2B2); also elsewhere on the board
/Select_Stage/HF_BPF_LOW/RF_OUT: TP26.1, U6.5 (1B2), U6.11 (2B2); also elsewhere on the board
/Select_Stage/RF_IN: U5.7 (1A), U5.9 (2A); also elsewhere on the board
/Select_Stage/Select_Out: R14.1, U6.7 (1A), U6.9 (2A); also elsewhere on the board
GND: C14.1, C15.2, C17.1, U5.1 (1~OE), U5.8 (GND), U5.15 (2~OE), U6.1 (1~OE), U6.8 (GND), U6.15 (2~OE); also elsewhere on the board
unnamed: C16.1, U5.3 (1B4), U5.13 (2B4)
unnamed: C16.2, U6.3 (1B4), U6.13 (2B4)

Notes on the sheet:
RF Passthough

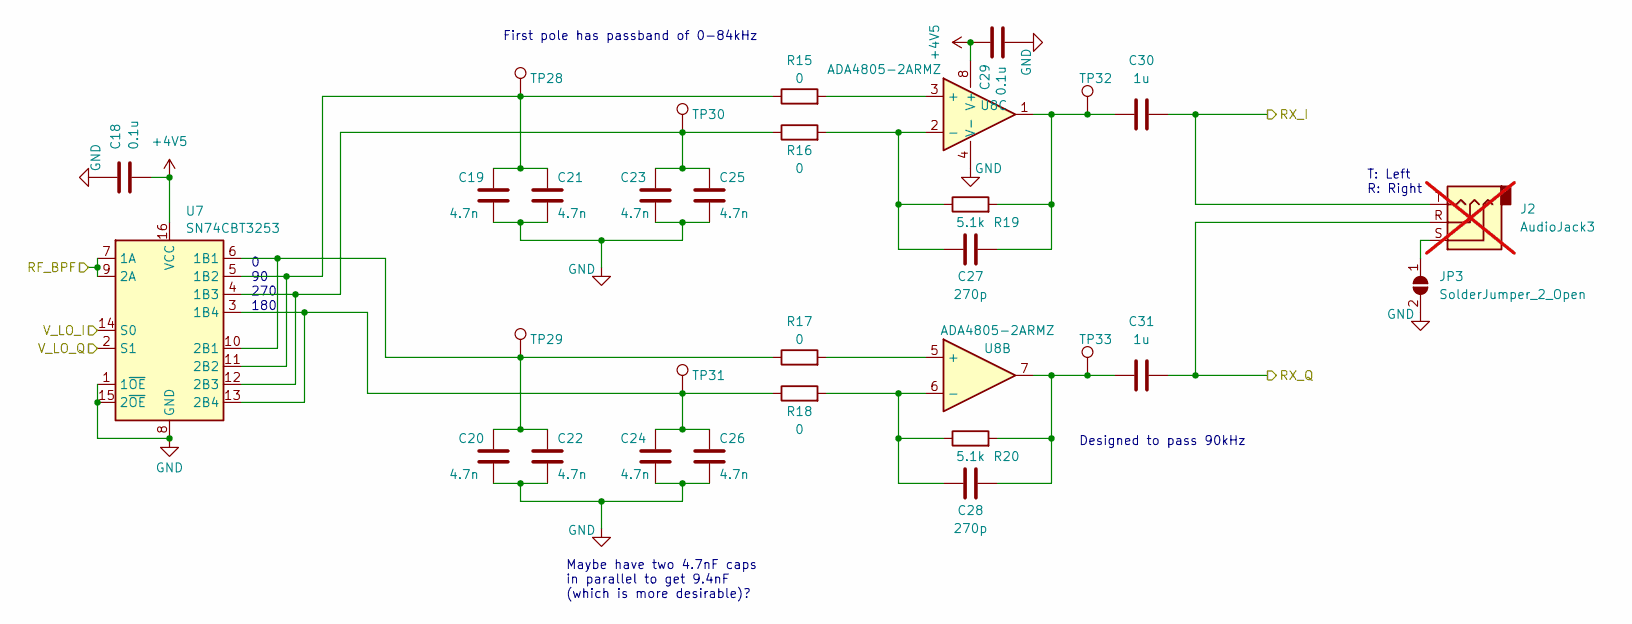
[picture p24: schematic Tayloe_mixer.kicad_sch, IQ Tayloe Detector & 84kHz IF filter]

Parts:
C18, C29: 0.1u; C_0805_2012Metric; LCSC C49678
C19, C20, C21, C22, C23, C24, C25, C26: 4.7n; C_0603_1608Metric; LCSC C883564
C27, C28: 270p; C_0402_1005Metric; LCSC C881990
C30, C31: 1u; C_0805_2012Metric; LCSC C28323
J2: AudioJack3; Jack_3.5mm_CUI_SJ1-3523N_Horizontal; not fitted
JP3: SolderJumper_2_Open; SolderJumper-2_P1.3mm_Open_RoundedPad1.0x1.5mm
R15, R16, R17, R18: 0; R_0805_2012Metric; LCSC C17477
R19, R20: 5.1k; R_0805_2012Metric; LCSC C27834
TP28, TP29, TP30, TP31, TP32, TP33: TestPoint; TestPoint_THTPad_D1.0mm_Drill0.5mm
U7: SN74CBT3253; SOP65P640X120-16N; LCSC C2674672
U8: ADA4805-2ARMZ; MSOP-8_3x3mm_P0.65mm; LCSC C208293

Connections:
+4V5: C18.2, C29.1, U7.16 (VCC), U8.8 (V+); also elsewhere on the board
/Controller/ADC_I_IN: C30.2, J2.T; also elsewhere on the board
/Controller/ADC_Q_IN: C31.2, J2.R; also elsewhere on the board
/Controller/V_LO_0: U7.14 (S0); also elsewhere on the board
/Controller/V_LO_1: U7.2 (S1); also elsewhere on the board
/Select_Stage/Select_Out: U7.7 (1A), U7.9 (2A); also elsewhere on the board
GND: C18.1, C19.2, C20.2, C21.2, C22.2, C23.2, C24.2, C25.2, C26.2, C29.2, JP3.2 (B), U7.1 (1~OE), U7.8 (GND), U7.15 (2~OE), U8.4 (V-); also elsewhere on the board
unnamed: C27.2, C30.1, R19.2, TP32.1, U8.1
unnamed: C28.2, C31.1, R20.2, TP33.1, U8.7
unnamed 45: J2.S, JP3.1 (A); also elsewhere on the board
unnamed: C20.1, C22.1, R17.1, TP29.1, U7.6 (1B1), U7.10 (2B1)
unnamed: C19.1, C21.1, R15.1, TP28.1, U7.5 (1B2), U7.11 (2B2)
unnamed: C23.1, C25.1, R16.1, TP30.1, U7.4 (1B3), U7.12 (2B3)
unnamed: C24.1, C26.1, R18.1, TP31.1, U7.3 (1B4), U7.13 (2B4)
unnamed: R15.2, U8.3 (+)
unnamed: C27.1, R16.2, R19.1, U8.2 (-)
unnamed: R17.2, U8.5 (+)
unnamed: C28.1, R18.2, R20.1, U8.6 (-)

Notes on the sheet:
First pole has passband of 0-84kHz
Maybe have two 4.7nF caps in parallel to get 9.4nF (which is more desirable)?
Designed to pass 90kHz
T: Left R: Right
0 90 270 180

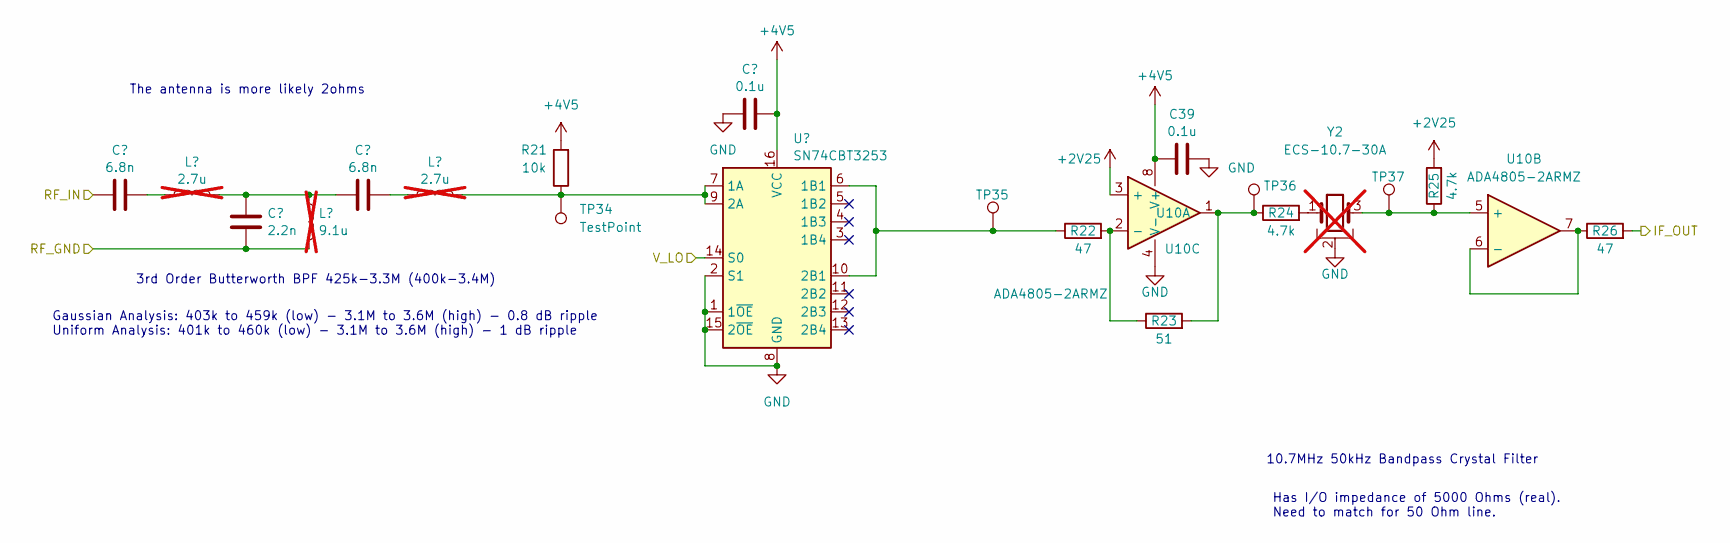
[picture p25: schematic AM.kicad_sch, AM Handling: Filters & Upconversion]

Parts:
C35, C37: 6.8n; C_0603_1608Metric; LCSC C1631
C36: 2.2n; C_0805_2012Metric; LCSC C28260
C38, C39: 0.1u; C_0805_2012Metric; LCSC C49678
L4, L6: 2.7u; L_Toroid_Vertical_L10.0mm_W5.0mm_P5.08mm; not fitted
L5: 9.1u; L_Toroid_Vertical_L10.0mm_W5.0mm_P5.08mm; not fitted
R21: 10k; R_0805_2012Metric; LCSC C17414
R22, R26: 47; R_0805_2012Metric; LCSC C17714
R23: 51; R_0805_2012Metric; LCSC C17738
R24, R25: 4.7k; R_0805_2012Metric; LCSC C17673
TP34, TP35, TP36, TP37: TestPoint; TestPoint_THTPad_D1.0mm_Drill0.5mm
U9: SN74CBT3253; SOP65P640X120-16N; LCSC C2674672
U10: ADA4805-2ARMZ; MSOP-8_3x3mm_P0.65mm; LCSC C208293
Y2: ECS-10.7-30A; Crystal_HC49-U-3Pin_Vertical; not fitted

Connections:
+2V25: R25.2, U10.3 (+); also elsewhere on the board
+4V5: C38.2, C39.1, R21.2, U9.16 (VCC), U10.8 (V+); also elsewhere on the board
/Controller/V_LO_2: U9.14 (S0); also elsewhere on the board
/Select_Stage/AM/IF_OUT: R26.2; also elsewhere on the board
/Select_Stage/AM/RF_GND: C36.2, L5.2; also elsewhere on the board
/Select_Stage/AM/RF_IN: C35.2; also elsewhere on the board
GND: C38.1, C39.2, U9.1 (1~OE), U9.2 (S1), U9.8 (GND), U9.15 (2~OE), U10.4 (V-), Y2.2; also elsewhere on the board
unnamed: C35.1, L4.1
unnamed: C36.1, C37.1, L4.2, L5.1
unnamed: C37.2, L6.1
unnamed 46: R23.2, R24.1, TP36.1, U10.1; also elsewhere on the board
unnamed: R24.2, Y2.1
unnamed: L6.2, R21.1, TP34.1, U9.7 (1A), U9.9 (2A)
unnamed: R22.1, TP35.1, U9.6 (1B1), U9.10 (2B1)
unnamed: R22.2, R23.1, U10.2 (-)
unnamed 74: R25.1, TP37.1, U10.5 (+), Y2.3; also elsewhere on the board
unnamed: R26.1, U10.6 (-), U10.7

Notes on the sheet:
Has I/O impedance of 5000 Ohms (real). Need to match for 50 Ohm line.
10.7MHz 50kHz Bandpass Crystal Filter
3rd Order Butterworth BPF 425k-3.3M (400k-3.4M)
The antenna is more likely 2ohms
Gaussian Analysis: 403k to 459k (low) - 3.1M to 3.6M (high) - 0.8 dB ripple Uniform Analysis: 401k to 460k (low) - 3.1M to 3.6M (high) - 1 dB ripple

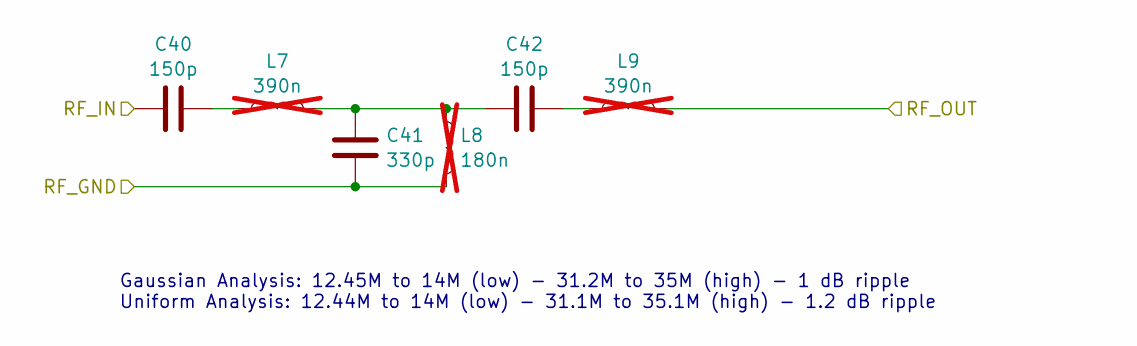
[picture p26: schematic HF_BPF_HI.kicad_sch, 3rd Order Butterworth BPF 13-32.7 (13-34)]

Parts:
C40, C42: 150p; C_0603_1608Metric; LCSC C1594
C41: 330p; C_0603_1608Metric; LCSC C1664
L7, L9: 390n; L_Toroid_Vertical_L10.0mm_W5.0mm_P5.08mm; not fitted
L8: 180n; L_Toroid_Vertical_L10.0mm_W5.0mm_P5.08mm; not fitted

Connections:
/Select_Stage/AM/RF_GND: C41.2, L8.2; also elsewhere on the board
/Select_Stage/HF_BPF_HI/RF_IN: C40.2; also elsewhere on the board
/Select_Stage/HF_BPF_HI/RF_OUT: L9.2; also elsewhere on the board
unnamed: C40.1, L7.1
unnamed: C41.1, C42.1, L7.2, L8.1
unnamed: C42.2, L9.1

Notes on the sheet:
Gaussian Analysis: 12.45M to 14M (low) - 31.2M to 35M (high) - 1 dB ripple Uniform Analysis: 12.44M to 14M (low) - 31.1M to 35.1M (high) - 1.2 dB ripple

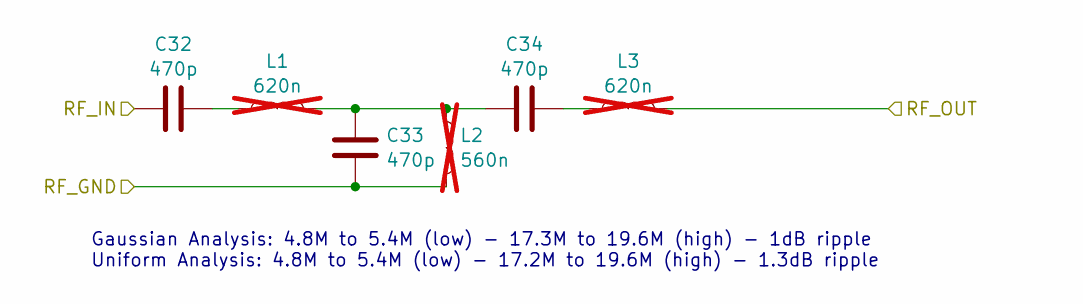
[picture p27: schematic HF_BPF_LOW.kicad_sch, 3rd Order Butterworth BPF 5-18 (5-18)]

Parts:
C32, C33, C34: 470p; C_0805_2012Metric; LCSC C1743
L1, L3: 620n; L_Toroid_Vertical_L10.0mm_W5.0mm_P5.08mm; not fitted
L2: 560n; L_Toroid_Vertical_L10.0mm_W5.0mm_P5.08mm; not fitted

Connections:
/Select_Stage/AM/RF_GND: C33.2, L2.2; also elsewhere on the board
/Select_Stage/HF_BPF_LOW/RF_IN: C32.2; also elsewhere on the board
/Select_Stage/HF_BPF_LOW/RF_OUT: L3.2; also elsewhere on the board
unnamed: C32.1, L1.1
unnamed: C33.1, C34.1, L1.2, L2.1
unnamed: C34.2, L3.1

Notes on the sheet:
Gaussian Analysis: 4.8M to 5.4M (low) - 17.3M to 19.6M (high) - 1dB ripple Uniform Analysis: 4.8M to 5.4M (low) - 17.2M to 19.6M (high) - 1.3dB ripple

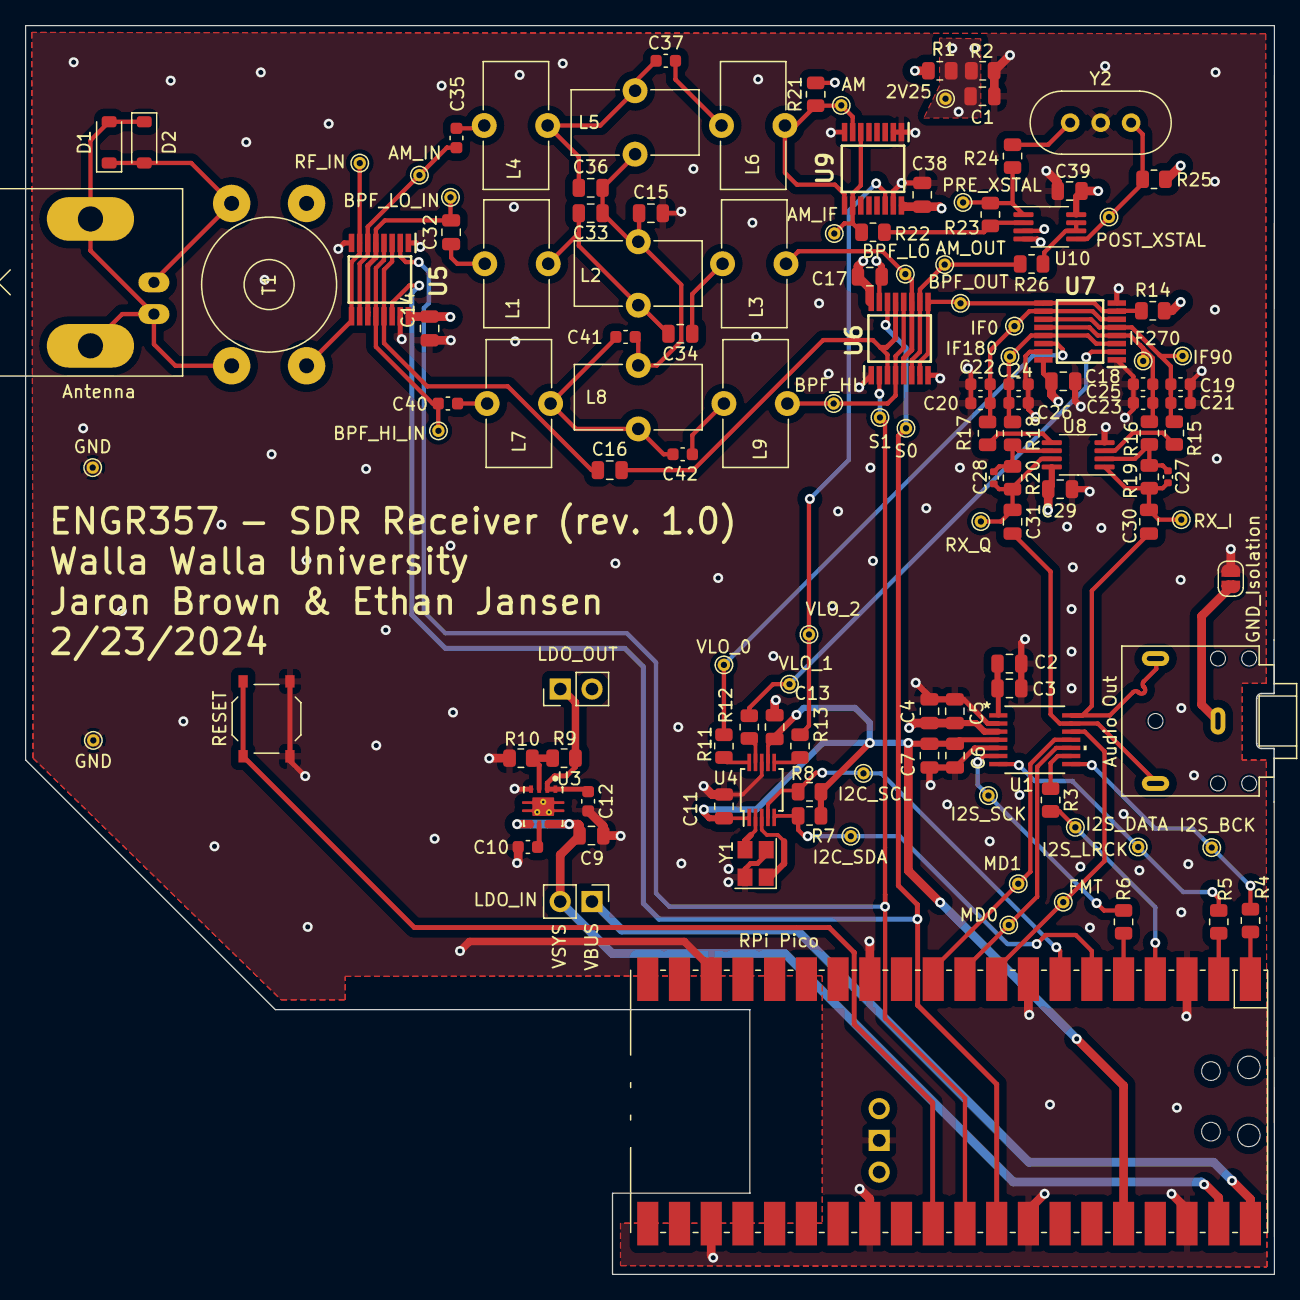
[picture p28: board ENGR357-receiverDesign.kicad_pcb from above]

Board: 4 copper layers, 100.0 x 100.0 mm, 132 parts (0 on the bottom side), 76 nets.

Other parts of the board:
Audio Out: AudioJack3; Jack_3.5mm_CUI_SJ1-3523N_Horizontal
POST_XSTAL: TestPoint; TestPoint_THTPad_D1.0mm_Drill0.5mm
PRE_XSTAL: TestPoint; TestPoint_THTPad_D1.0mm_Drill0.5mm
RPi Pico: PicoW; RPi_PicoW_SMD_TH

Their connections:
+3V3: RPi Pico.36 (3V3); also elsewhere on the board
/Controller/ADC_I_IN: Audio Out.T; also elsewhere on the board
/Controller/ADC_Q_IN: Audio Out.R; also elsewhere on the board
/Controller/FMT: RPi Pico.9 (GPIO6); also elsewhere on the board
/Controller/I2C0-SCL: RPi Pico.7 (GPIO5); also elsewhere on the board
/Controller/I2C0-SDA: RPi Pico.6 (GPIO4); also elsewhere on the board
/Controller/I2S_DATA: RPi Pico.4 (GPIO2); also elsewhere on the board
/Controller/MD0: RPi Pico.10 (GPIO7); also elsewhere on the board
/Controller/MD1: RPi Pico.11 (GPIO8); also elsewhere on the board
/Controller/Select-S0: RPi Pico.32 (GPIO27_ADC1); also elsewhere on the board
/Controller/Select-S1: RPi Pico.31 (GPIO26_ADC0); also elsewhere on the board
GND: RPi Pico.3 (GND), RPi Pico.8 (GND), RPi Pico.13 (GND), RPi Pico.18 (GND), RPi Pico.23 (GND), RPi Pico.28 (GND), RPi Pico.33 (AGND), RPi Pico.38 (GND), RPi Pico.42 (GND); also elsewhere on the board
unnamed 42: RPi Pico.40 (VBUS); also elsewhere on the board
unnamed 43: RPi Pico.39 (VSYS); also elsewhere on the board
unnamed 45: Audio Out.S; also elsewhere on the board
unnamed 46: PRE_XSTAL.1; also elsewhere on the board
unnamed 50: RPi Pico.1 (GPIO0); also elsewhere on the board
unnamed 51: RPi Pico.2 (GPIO1); also elsewhere on the board
unnamed 52: RPi Pico.5 (GPIO3); also elsewhere on the board
unnamed 53: RPi Pico.30 (RUN); also elsewhere on the board
unnamed 74: POST_XSTAL.1; also elsewhere on the board

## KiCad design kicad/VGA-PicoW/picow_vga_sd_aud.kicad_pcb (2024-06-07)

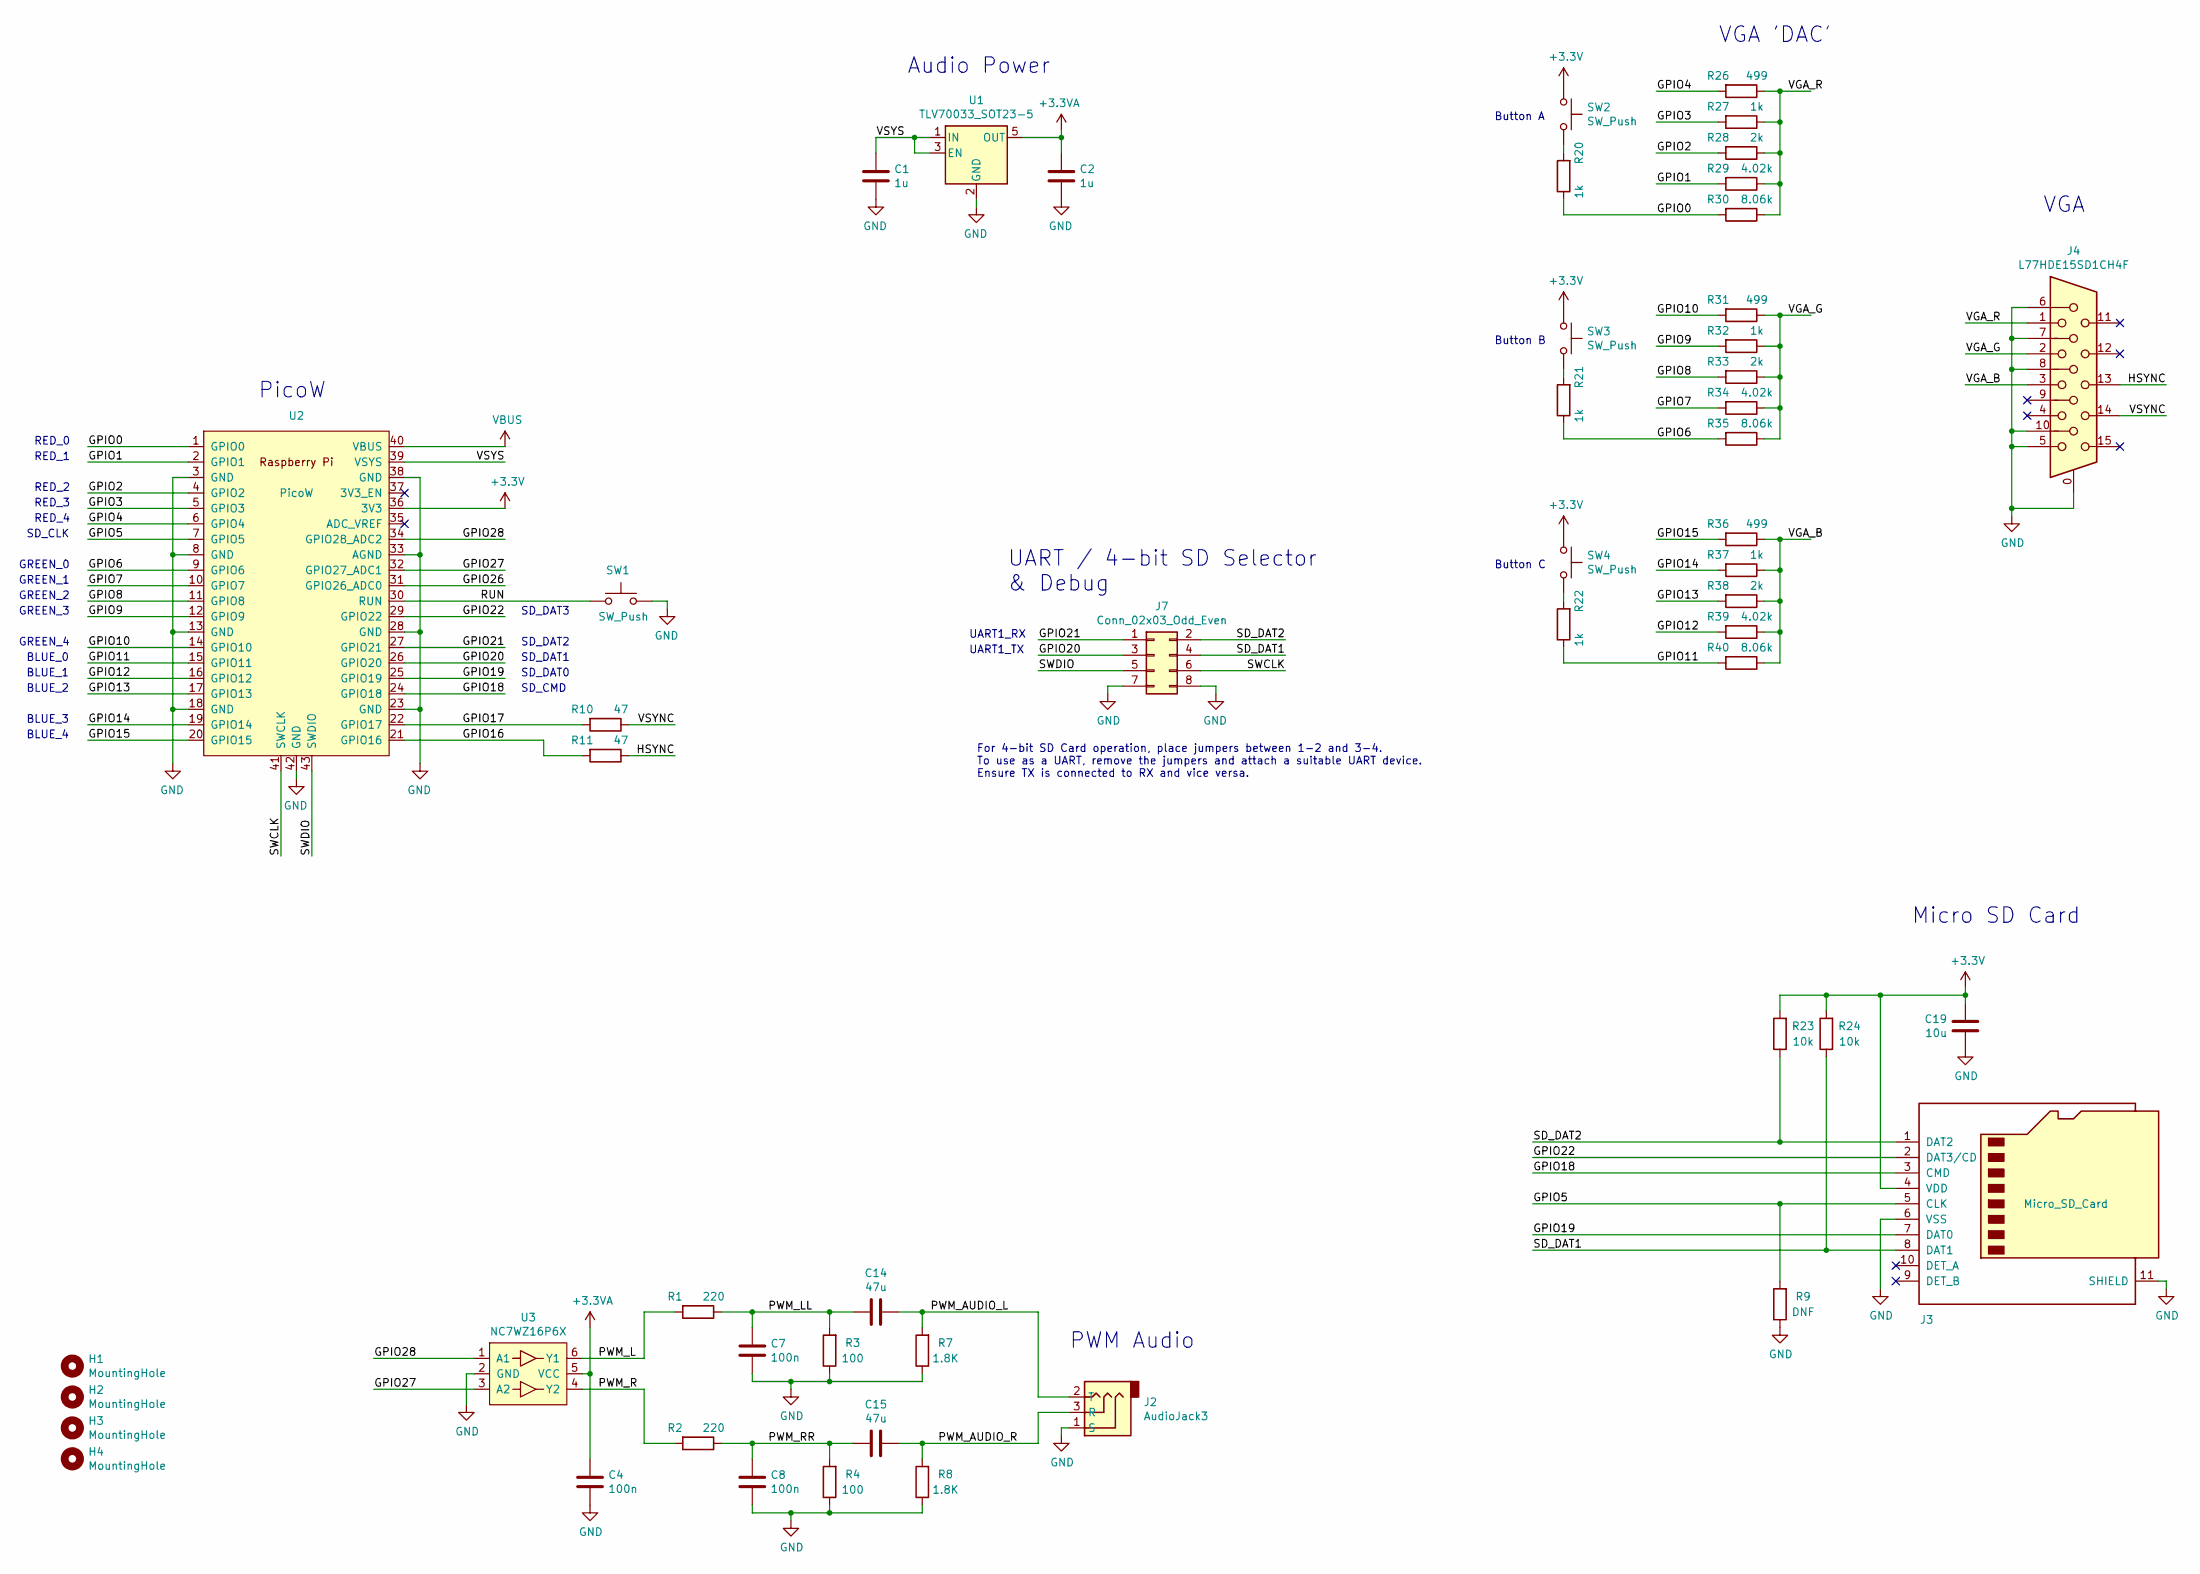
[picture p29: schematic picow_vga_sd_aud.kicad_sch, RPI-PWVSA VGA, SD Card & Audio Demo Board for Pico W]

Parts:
C1, C2: 1u; C_0603_1608Metric
C4, C7, C8: 100n; C_0402_1005Metric
C14, C15: 47u; C_0805_2012Metric
C19: 10u; C_0603_1608Metric
H1, H2, H3, H4: MountingHole; MountingHole_2.7mm_M2.5
J2: AudioJack3; CUI_SJ-3523-audio-jack
J3: Micro_SD_Card; microSD_HC_Molex_104031-0811
J4: L77HDE15SD1CH4F; DSUB-15-L77HDE15SD1CH4F
J7: Conn_02x03_Odd_Even; PinHeader_2x04_P2.54mm_Vertical
R1, R2: 220; R_0402_1005Metric
R3, R4: 100; R_0402_1005Metric
R7, R8: 1.8K; R_0402_1005Metric
R9: DNF; R_0402_1005Metric
R10, R11: 47; R_0402_1005Metric
R20, R21, R22, R27, R32, R37: 1k; R_0402_1005Metric
R23, R24: 10k; R_0402_1005Metric
R26, R31, R36: 499; R_0402_1005Metric
R28, R33, R38: 2k; R_0402_1005Metric
R29, R34, R39: 4.02k; R_0402_1005Metric
R30, R35, R40: 8.06k; R_0402_1005Metric
SW1, SW2, SW3, SW4: SW_Push; SW_Push_1P1T_NO_Vertical_Wuerth_434133025816
U1: TLV70033_SOT23-5; SOT-23-5
U2: PicoW; RPi_PicoW_SMD_TH
U3: NC7WZ16P6X; SOT-363_SC-70-6

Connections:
+3.3VA: C2.1, C4.1, U1.5 (OUT), U3.5 (VCC)
+3V3: C19.1, J3.4 (VDD), R23.2, R24.2, SW2.1, SW3.1, SW4.1, U2.36 (3V3)
/GPIO0: R20.1, R30.2, U2.1 (GPIO0)
/GPIO1: R29.2, U2.2 (GPIO1)
/GPIO2: R28.2, U2.4 (GPIO2)
/GPIO3: R27.2, U2.5 (GPIO3)
/GPIO4: R26.2, U2.6 (GPIO4)
/GPIO5: J3.5 (CLK), R9.2, U2.7 (GPIO5)
/GPIO6: R21.1, R35.2, U2.9 (GPIO6)
/GPIO7: R34.2, U2.10 (GPIO7)
/GPIO8: R33.2, U2.11 (GPIO8)
/GPIO9: R32.2, U2.12 (GPIO9)
/GPIO10: R31.2, U2.14 (GPIO10)
/GPIO11: R22.1, R40.2, U2.15 (GPIO11)
/GPIO12: R39.2, U2.16 (GPIO12)
/GPIO13: R38.2, U2.17 (GPIO13)
/GPIO14: R37.2, U2.19 (GPIO14)
/GPIO15: R36.2, U2.20 (GPIO15)
/GPIO16: R11.2, U2.21 (GPIO16)
/GPIO17: R10.2, U2.22 (GPIO17)
/GPIO18: J3.3 (CMD), U2.24 (GPIO18)
/GPIO19: J3.7 (DAT0), U2.25 (GPIO19)
/GPIO20: J7.3, U2.26 (GPIO20)
/GPIO21: J7.1, U2.27 (GPIO21)
/GPIO22: J3.2 (DAT3/CD), U2.29 (GPIO22)
/GPIO26: U2.31 (GPIO26_ADC0)
/GPIO27: U2.32 (GPIO27_ADC1), U3.3 (A2)
/GPIO28: U2.34 (GPIO28_ADC2), U3.1 (A1)
/HSYNC: J4.13, R11.1
/PWM_AUDIO_L: C14.1, J2.2 (T), R7.2
/PWM_AUDIO_R: C15.1, J2.3 (R), R8.2
/PWM_L: R1.2, U3.6 (Y1)
/PWM_LL: C7.1, C14.2, R1.1, R3.2
/PWM_R: R2.2, U3.4 (Y2)
/PWM_RR: C8.1, C15.2, R2.1, R4.2
/RUN: SW1.1, U2.30 (RUN)
/SD_DAT1: J3.8 (DAT1), J7.4, R24.1
/SD_DAT2: J3.1 (DAT2), J7.2, R23.1
/SWCLK: J7.6, U2.41 (SWCLK)
/SWDIO: J7.5, U2.43 (SWDIO)
/VGA_B: J4.3, R36.1, R37.1, R38.1, R39.1, R40.1
/VGA_G: J4.2, R31.1, R32.1, R33.1, R34.1, R35.1
/VGA_R: J4.1, R26.1, R27.1, R28.1, R29.1, R30.1
/VSYNC: J4.14, R10.1
/VSYS: C1.1, U1.1 (IN), U1.3 (EN), U2.39 (VSYS)
GND: C1.2, C2.2, C4.2, C7.2, C8.2, C19.2, J2.1 (S), J3.6 (VSS), J3.11 (SHIELD), J4.0, J4.5, J4.6, J4.7, J4.8, J4.10, J7.7, J7.8, R3.1, R4.1, R7.1, R8.1, R9.1, SW1.2, U1.2 (GND), U2.3 (GND), U2.8 (GND), U2.13 (GND), U2.18 (GND), U2.23 (GND), U2.28 (GND), U2.33 (AGND), U2.38 (GND), U2.42 (GND), U3.2 (GND)
unnamed: R20.2, SW2.2
unnamed: R21.2, SW3.2
unnamed: R22.2, SW4.2
VBUS: U2.40 (VBUS)

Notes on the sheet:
GREEN_0
RED_3
RED_1
SD_DAT2
Button A
VGA
SD_CLK
BLUE_4
BLUE_0
UART1_TX
SD_DAT1
RED_4
PicoW
For 4-bit SD Card operation, place jumpers between 1-2 and 3-4. To use as a UART, remove the jumpers and attach a suitable UART device. Ensure TX is connected to RX and vice versa.
UART1_RX
VGA 'DAC'
Button B
Button C
GREEN_1
UART / 4-bit SD Selector & Debug
SD_DAT0
BLUE_3
SD_CMD
SD_DAT3
Micro SD Card
GREEN_4
RED_2
GREEN_2
Audio Power
PWM Audio
BLUE_1
GREEN_3
BLUE_2
RED_0

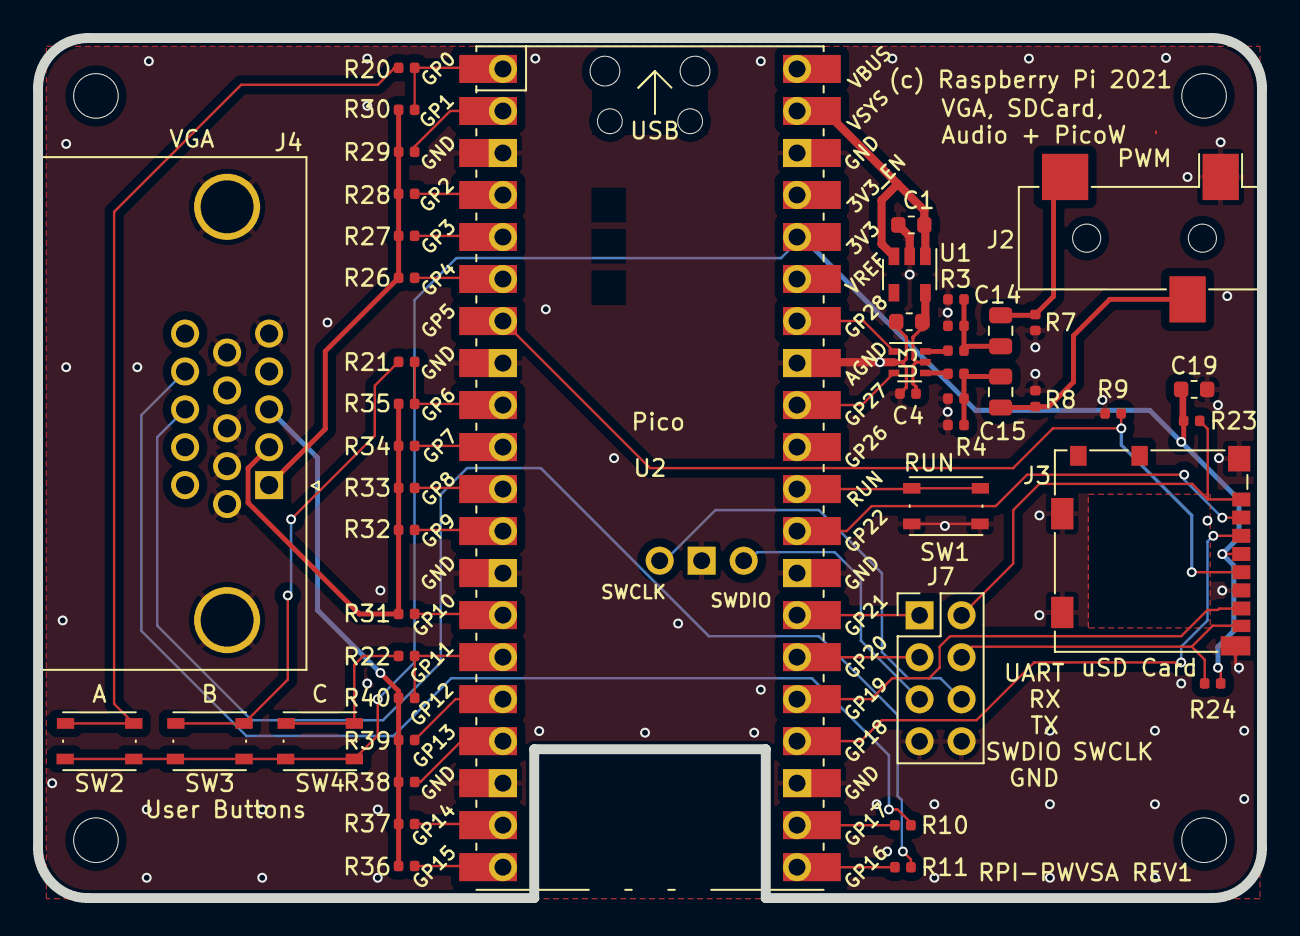
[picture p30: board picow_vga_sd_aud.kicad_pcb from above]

Board: 4 copper layers, 74.0 x 52.0 mm, 52 parts (0 on the bottom side), 48 nets.

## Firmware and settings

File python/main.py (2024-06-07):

#     All commands consist of an identifier, followed by one or more parameters delinieated by commas, then a newline.
#     i.e.:
#     COMMAND,<param1>,<param2><LF>
#     
#     A command will return OK<LF> if successful, and ERROR<LF> if not. Some commands (particuarly transmit commands)
#     may take a significant amount of time to return.
#     
#     Sending a command which takes parameters, without sending the parameters, will return the set parameters.
#     
#     Frequency Settings:
#     
#     FREQ,<freq>     - Set the center freq of the receiver, in Hz.
#     END, 			  - Ends the session.

from machine import Pin
from radio import Radio
import si5351

Pin('WL_GPIO0', Pin.OUT).value(1) # Pico W Power LED
synth = si5351.SI5351( data=Pin(4), clock=Pin(5), addr=0x60 )
frequency = 7000000
band = 1
r = Radio( synth, frequency, band )
r.run()

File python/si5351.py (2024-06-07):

# The MIT License (MIT)
#
# Copyright (c) 2017 Tony DiCola for Adafruit Industries
#
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
# THE SOFTWARE IS PROVIDED "AS IS", WITHOUT WARRANTY OF ANY KIND, EXPRESS OR
# IMPLIED, INCLUDING BUT NOT LIMITED TO THE WARRANTIES OF MERCHANTABILITY,
# FITNESS FOR A PARTICULAR PURPOSE AND NONINFRINGEMENT. IN NO EVENT SHALL THE
# AUTHORS OR COPYRIGHT HOLDERS BE LIABLE FOR ANY CLAIM, DAMAGES OR OTHER
# LIABILITY, WHETHER IN AN ACTION OF CONTRACT, TORT OR OTHERWISE, ARISING FROM,
# OUT OF OR IN CONNECTION WITH THE SOFTWARE OR THE USE OR OTHER DEALINGS IN
# THE SOFTWARE.
"""
`adafruit_si5351`
====================================================

CircuitPython module to control the SI5351 clock generator.  See
examples/simpletest.py for a demo of the usage.  This is based on the Arduino
library at: https://github.com/adafruit/Adafruit_Si5351_Library/

* Author(s): Tony DiCola
"""
import math

from micropython import const

import machine
from machine import I2C
from machine import Pin


# pylint: disable=bad-whitespace
# Internal constants:
_SI5351_ADDRESS = const(0x60)  # Assumes ADDR pin = low
_SI5351_READBIT = const(0x01)
_SI5351_CRYSTAL_FREQUENCY = 27000700.02  # Fixed 27MHz crystal on board.
_SI5351_REGISTER_0_DEVICE_STATUS = const(0)
_SI5351_REGISTER_1_INTERRUPT_STATUS_STICKY = const(1)
_SI5351_REGISTER_2_INTERRUPT_STATUS_MASK = const(2)
_SI5351_REGISTER_3_OUTPUT_ENABLE_CONTROL = const(3)
_SI5351_REGISTER_9_OEB_PIN_ENABLE_CONTROL = const(9)
_SI5351_REGISTER_15_PLL_INPUT_SOURCE = const(15)
_SI5351_REGISTER_16_CLK0_CONTROL = const(16)
_SI5351_REGISTER_17_CLK1_CONTROL = const(17)
_SI5351_REGISTER_18_CLK2_CONTROL = const(18)
_SI5351_REGISTER_19_CLK3_CONTROL = const(19)
_SI5351_REGISTER_20_CLK4_CONTROL = const(20)
_SI5351_REGISTER_21_CLK5_CONTROL = const(21)
_SI5351_REGISTER_22_CLK6_CONTROL = const(22)
_SI5351_REGISTER_23_CLK7_CONTROL = const(23)
_SI5351_REGISTER_24_CLK3_0_DISABLE_STATE = const(24)
_SI5351_REGISTER_25_CLK7_4_DISABLE_STATE = const(25)
_SI5351_REGISTER_42_MULTISYNTH0_PARAMETERS_1 = const(42)
_SI5351_REGISTER_43_MULTISYNTH0_PARAMETERS_2 = const(43)
_SI5351_REGISTER_44_MULTISYNTH0_PARAMETERS_3 = const(44)
_SI5351_REGISTER_45_MULTISYNTH0_PARAMETERS_4 = const(45)
_SI5351_REGISTER_46_MULTISYNTH0_PARAMETERS_5 = const(46)
_SI5351_REGISTER_47_MULTISYNTH0_PARAMETERS_6 = const(47)
_SI5351_REGISTER_48_MULTISYNTH0_PARAMETERS_7 = const(48)
_SI5351_REGISTER_49_MULTISYNTH0_PARAMETERS_8 = const(49)
_SI5351_REGISTER_50_MULTISYNTH1_PARAMETERS_1 = const(50)
_SI5351_REGISTER_51_MULTISYNTH1_PARAMETERS_2 = const(51)
_SI5351_REGISTER_52_MULTISYNTH1_PARAMETERS_3 = const(52)
_SI5351_REGISTER_53_MULTISYNTH1_PARAMETERS_4 = const(53)
_SI5351_REGISTER_54_MULTISYNTH1_PARAMETERS_5 = const(54)
_SI5351_REGISTER_55_MULTISYNTH1_PARAMETERS_6 = const(55)
_SI5351_REGISTER_56_MULTISYNTH1_PARAMETERS_7 = const(56)
_SI5351_REGISTER_57_MULTISYNTH1_PARAMETERS_8 = const(57)
_SI5351_REGISTER_58_MULTISYNTH2_PARAMETERS_1 = const(58)
_SI5351_REGISTER_59_MULTISYNTH2_PARAMETERS_2 = const(59)
_SI5351_REGISTER_60_MULTISYNTH2_PARAMETERS_3 = const(60)
_SI5351_REGISTER_61_MULTISYNTH2_PARAMETERS_4 = const(61)
_SI5351_REGISTER_62_MULTISYNTH2_PARAMETERS_5 = const(62)
_SI5351_REGISTER_63_MULTISYNTH2_PARAMETERS_6 = const(63)
_SI5351_REGISTER_64_MULTISYNTH2_PARAMETERS_7 = const(64)
_SI5351_REGISTER_65_MULTISYNTH2_PARAMETERS_8 = const(65)
_SI5351_REGISTER_66_MULTISYNTH3_PARAMETERS_1 = const(66)
_SI5351_REGISTER_67_MULTISYNTH3_PARAMETERS_2 = const(67)
_SI5351_REGISTER_68_MULTISYNTH3_PARAMETERS_3 = const(68)
_SI5351_REGISTER_69_MULTISYNTH3_PARAMETERS_4 = const(69)
_SI5351_REGISTER_70_MULTISYNTH3_PARAMETERS_5 = const(70)
_SI5351_REGISTER_71_MULTISYNTH3_PARAMETERS_6 = const(71)
_SI5351_REGISTER_72_MULTISYNTH3_PARAMETERS_7 = const(72)
_SI5351_REGISTER_73_MULTISYNTH3_PARAMETERS_8 = const(73)
_SI5351_REGISTER_74_MULTISYNTH4_PARAMETERS_1 = const(74)
_SI5351_REGISTER_75_MULTISYNTH4_PARAMETERS_2 = const(75)
_SI5351_REGISTER_76_MULTISYNTH4_PARAMETERS_3 = const(76)
_SI5351_REGISTER_77_MULTISYNTH4_PARAMETERS_4 = const(77)
_SI5351_REGISTER_78_MULTISYNTH4_PARAMETERS_5 = const(78)
_SI5351_REGISTER_79_MULTISYNTH4_PARAMETERS_6 = const(79)
_SI5351_REGISTER_80_MULTISYNTH4_PARAMETERS_7 = const(80)
_SI5351_REGISTER_81_MULTISYNTH4_PARAMETERS_8 = const(81)
_SI5351_REGISTER_82_MULTISYNTH5_PARAMETERS_1 = const(82)
_SI5351_REGISTER_83_MULTISYNTH5_PARAMETERS_2 = const(83)
_SI5351_REGISTER_84_MULTISYNTH5_PARAMETERS_3 = const(84)
_SI5351_REGISTER_85_MULTISYNTH5_PARAMETERS_4 = const(85)
_SI5351_REGISTER_86_MULTISYNTH5_PARAMETERS_5 = const(86)
_SI5351_REGISTER_87_MULTISYNTH5_PARAMETERS_6 = const(87)
_SI5351_REGISTER_88_MULTISYNTH5_PARAMETERS_7 = const(88)
_SI5351_REGISTER_89_MULTISYNTH5_PARAMETERS_8 = const(89)
_SI5351_REGISTER_90_MULTISYNTH6_PARAMETERS = const(90)
_SI5351_REGISTER_91_MULTISYNTH7_PARAMETERS = const(91)
_SI5351_REGISTER_092_CLOCK_6_7_OUTPUT_DIVIDER = const(92)
_SI5351_REGISTER_165_CLK0_INITIAL_PHASE_OFFSET = const(165)
_SI5351_REGISTER_166_CLK1_INITIAL_PHASE_OFFSET = const(166)
_SI5351_REGISTER_167_CLK2_INITIAL_PHASE_OFFSET = const(167)
_SI5351_REGISTER_168_CLK3_INITIAL_PHASE_OFFSET = const(168)
_SI5351_REGISTER_169_CLK4_INITIAL_PHASE_OFFSET = const(169)
_SI5351_REGISTER_170_CLK5_INITIAL_PHASE_OFFSET = const(170)
_SI5351_REGISTER_177_PLL_RESET = const(177)

_SI5351_CLK_DRIVE_STRENGTH_MASK = const(3<<0)
STRENGTH_2MA   = const(0<<0)
STRENGTH_4MA   = const(1<<0)
STRENGTH_6MA   = const(2<<0)
STRENGTH_8MA   = const(3<<0)

_SI5351_CRYSTAL_LOAD = const(183)
_SI5351_CRYSTAL_LOAD_MASK = const(3<<6)
SI5351_CRYSTAL_LOAD_0PF = const(0<<6)
SI5351_CRYSTAL_LOAD_6PF = const(1<<6)
SI5351_CRYSTAL_LOAD_8PF = const(2<<6)
SI5351_CRYSTAL_LOAD_10PF = const(3<<6)


SI5351_FREQ_MULT = const(100)
SI5351_MULTISYNTH_DIVBY4_FREQ = const(150000000)

# User-facing constants:
R_DIV_1 = 0
R_DIV_2 = 1
R_DIV_4 = 2
R_DIV_8 = 3
R_DIV_16 = 4
R_DIV_32 = 5
R_DIV_64 = 6
R_DIV_128 = 7
# pylint: enable=bad-whitespace


# Disable invalid name because p1, p2, p3 variables are false positives.
# These are legitimate register names and adding more characters obfuscates
# the intention of the code.
# pylint: disable=invalid-name

# Disable protected access warning because inner classes by design need and use
# access to protected members.
# pylint: disable=protected-access

# Another silly pylint check to disable, it has no context of the complexity
# of R divider values and explicit unrolling of them into multiple if cases
# and return statements.  Disable.
# pylint: disable=too-many-return-statements
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

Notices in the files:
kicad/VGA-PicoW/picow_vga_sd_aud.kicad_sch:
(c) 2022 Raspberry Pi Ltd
